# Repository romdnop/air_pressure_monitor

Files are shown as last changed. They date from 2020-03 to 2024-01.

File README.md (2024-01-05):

# About

Design files of an interface board for automotive application, the purpose of the board is data acquisition from air pressure sensors, CAN-Bus data sniffing and its relaying through one of the available interfaces.

# Features

* STM32F072 as a control MCU
* One side components placement
* Reverse-polarity protection, over-voltage protection and engine start surge voltage protection as decribed in [here](https://www.ti.com/lit/an/snva717/snva717.pdf)
* Support of two air-pressure sensors with 4-20mA interface
* USBx1
* CANx1
* RS485x1
* Support of extension boards with 2.54mm step (makes prototyping easier)

# Schematics
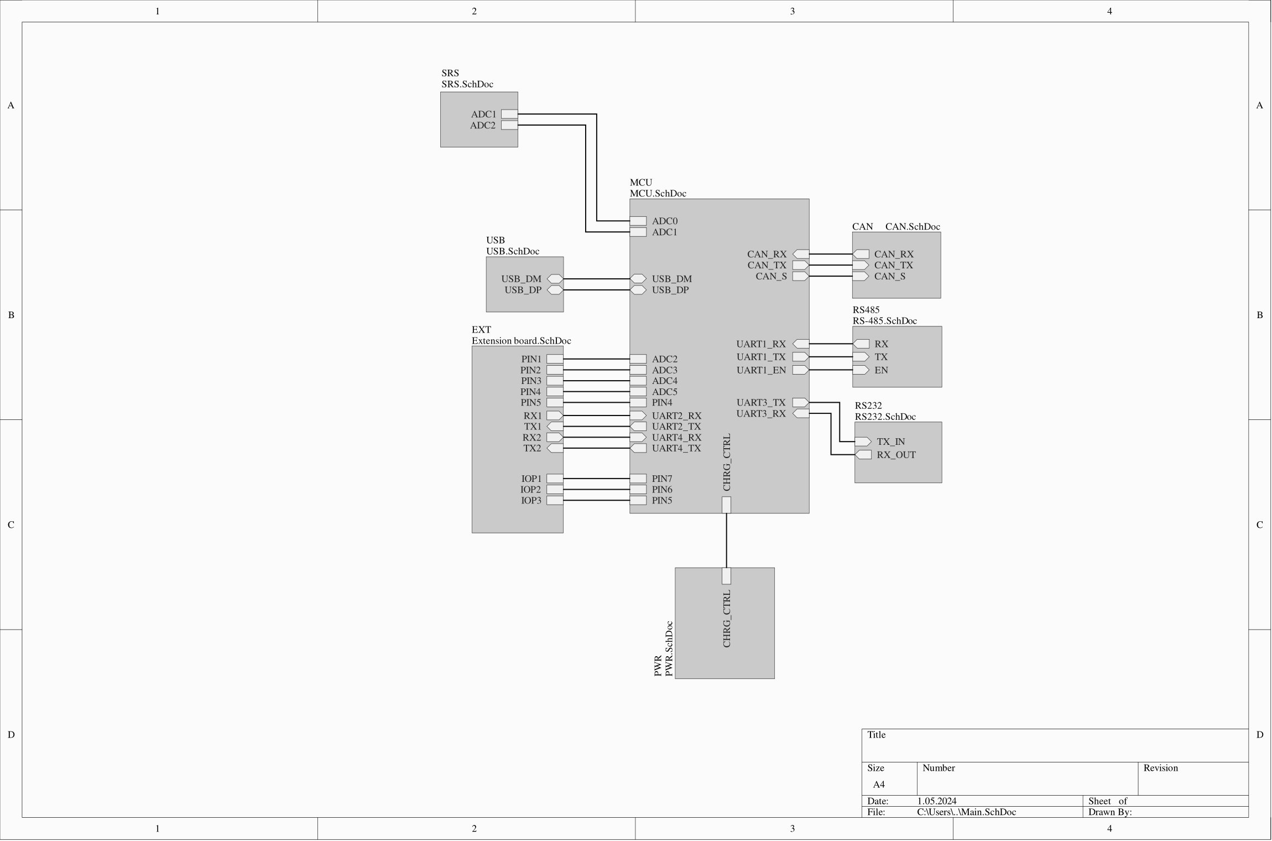
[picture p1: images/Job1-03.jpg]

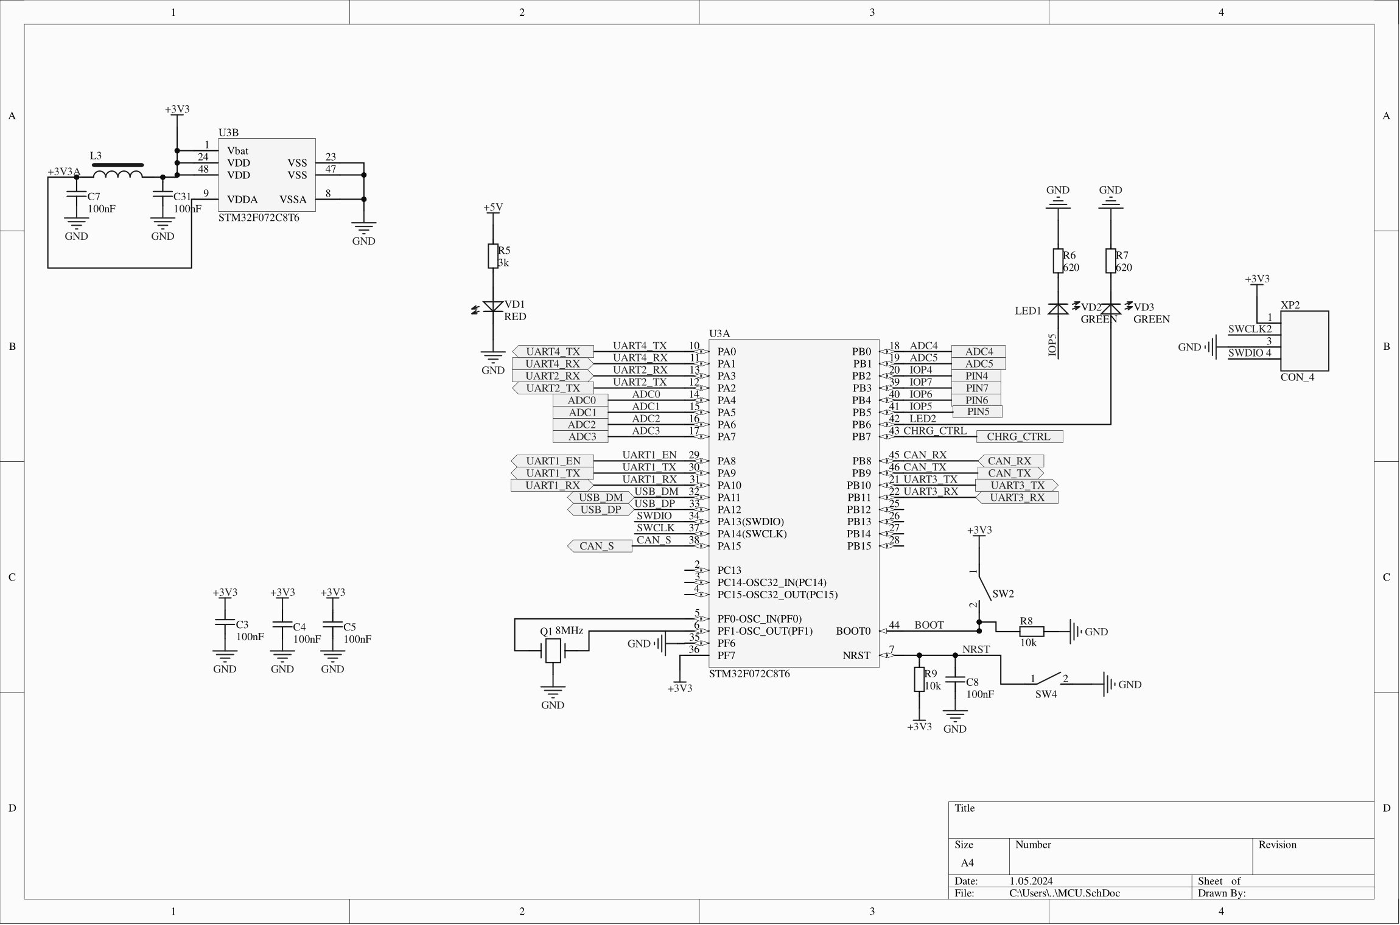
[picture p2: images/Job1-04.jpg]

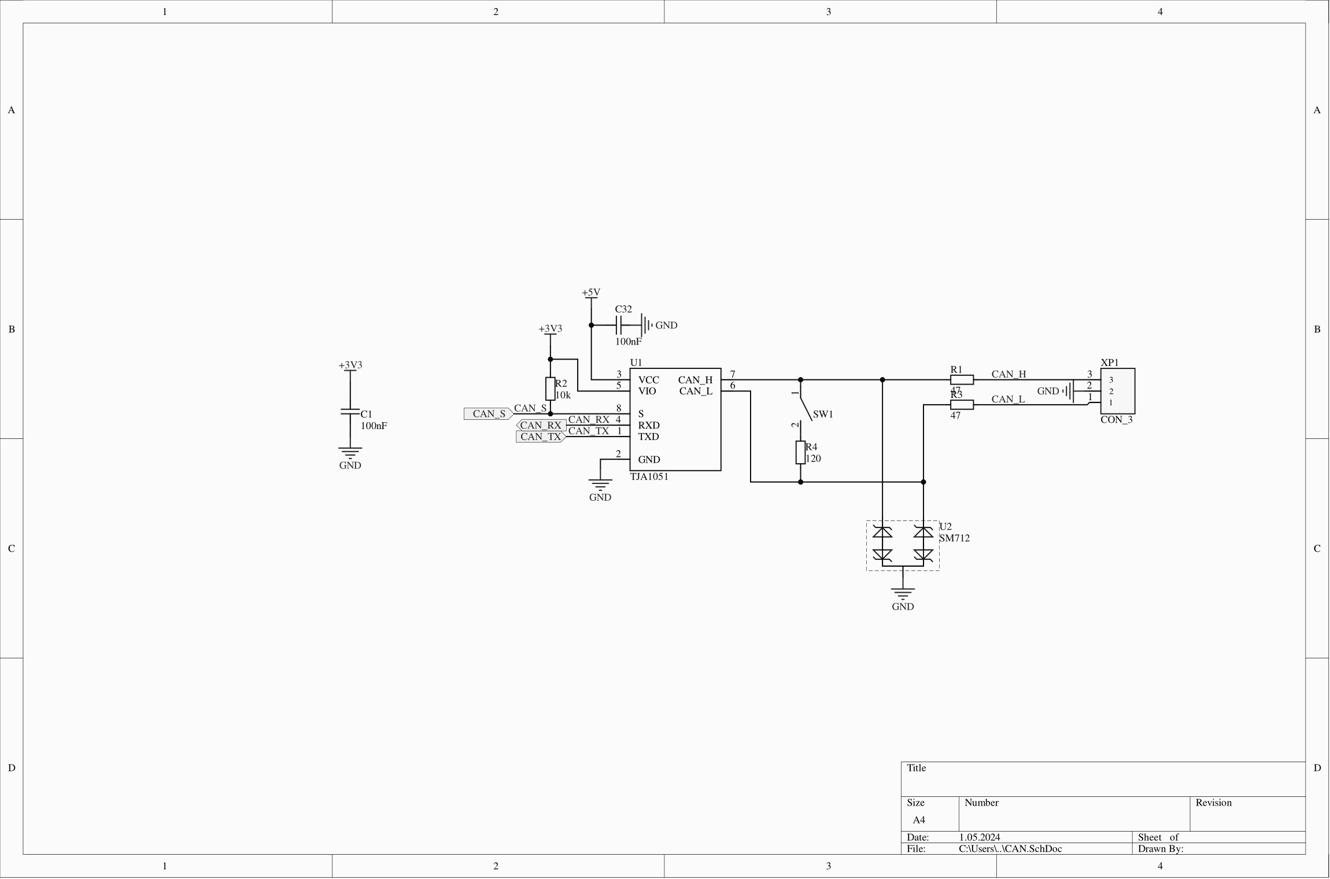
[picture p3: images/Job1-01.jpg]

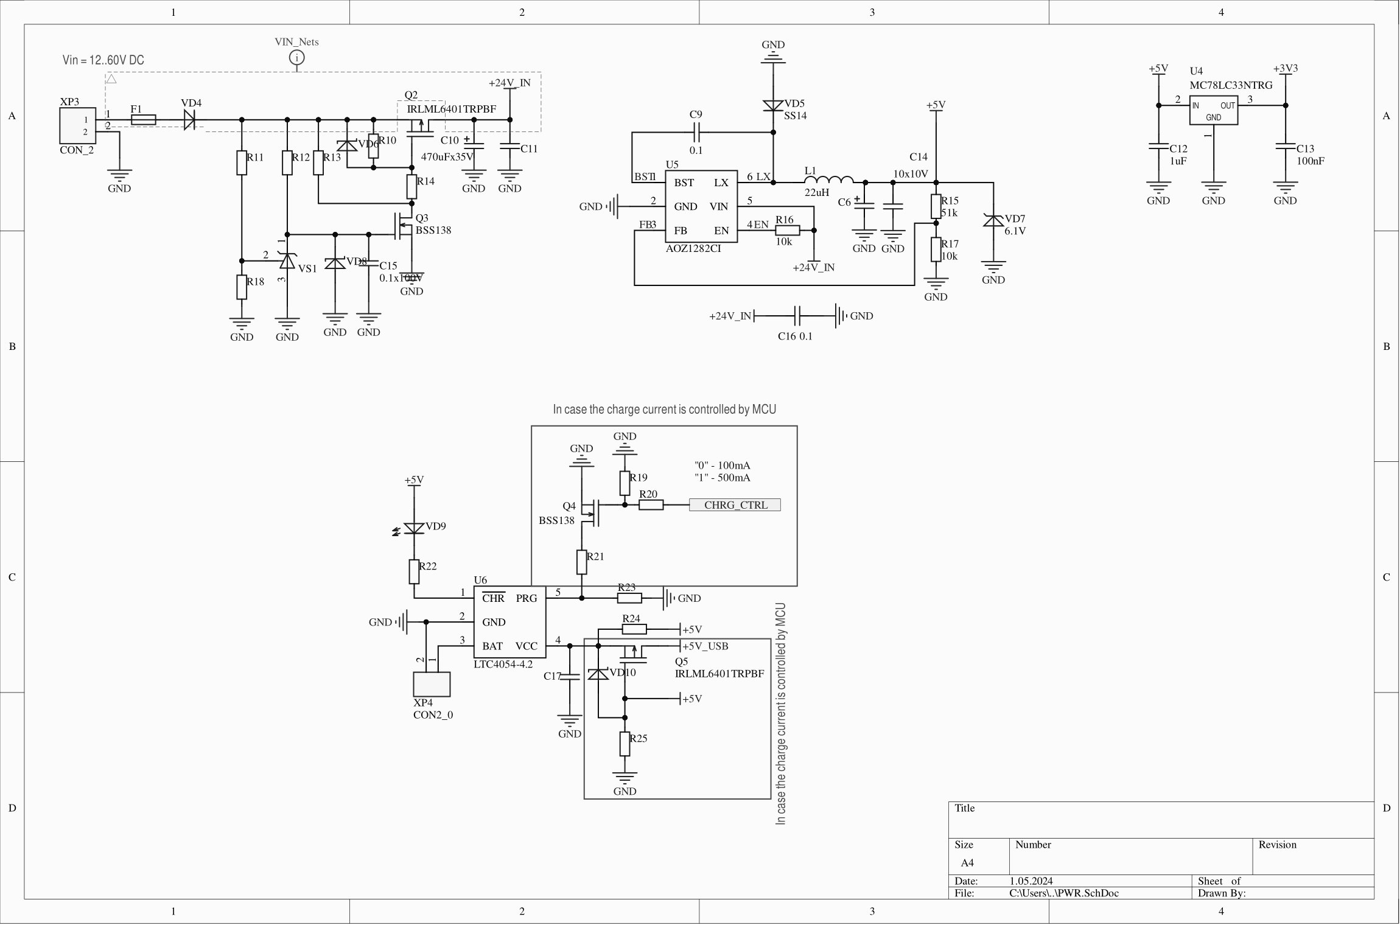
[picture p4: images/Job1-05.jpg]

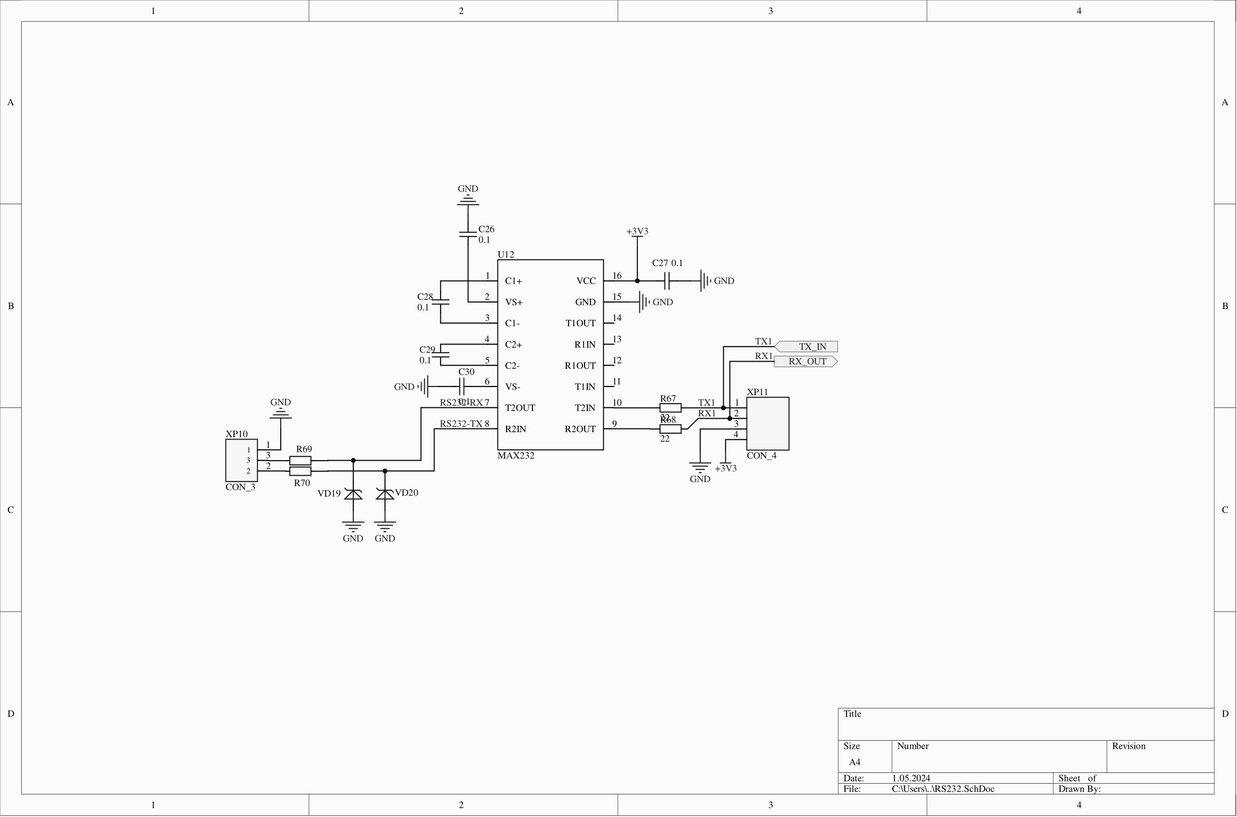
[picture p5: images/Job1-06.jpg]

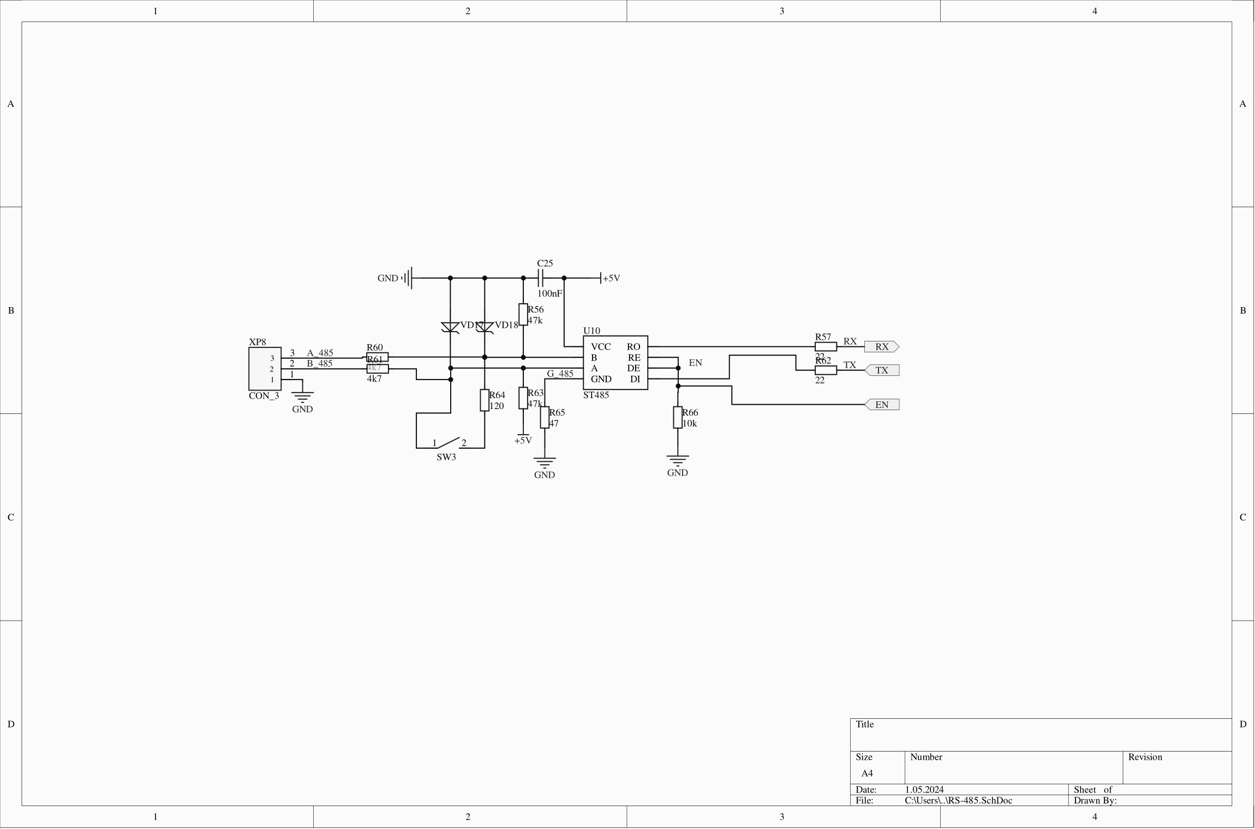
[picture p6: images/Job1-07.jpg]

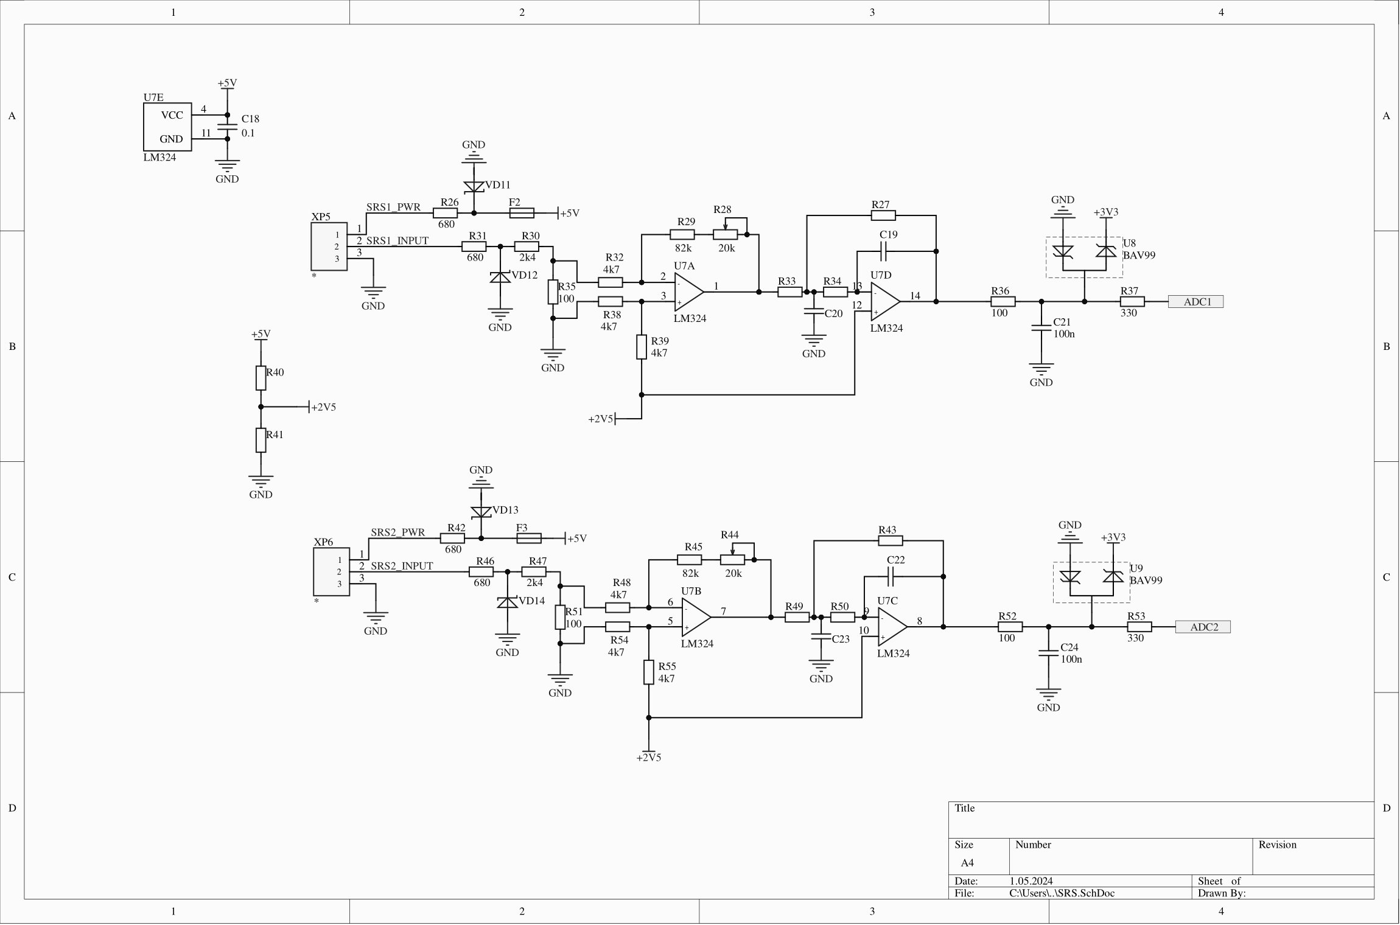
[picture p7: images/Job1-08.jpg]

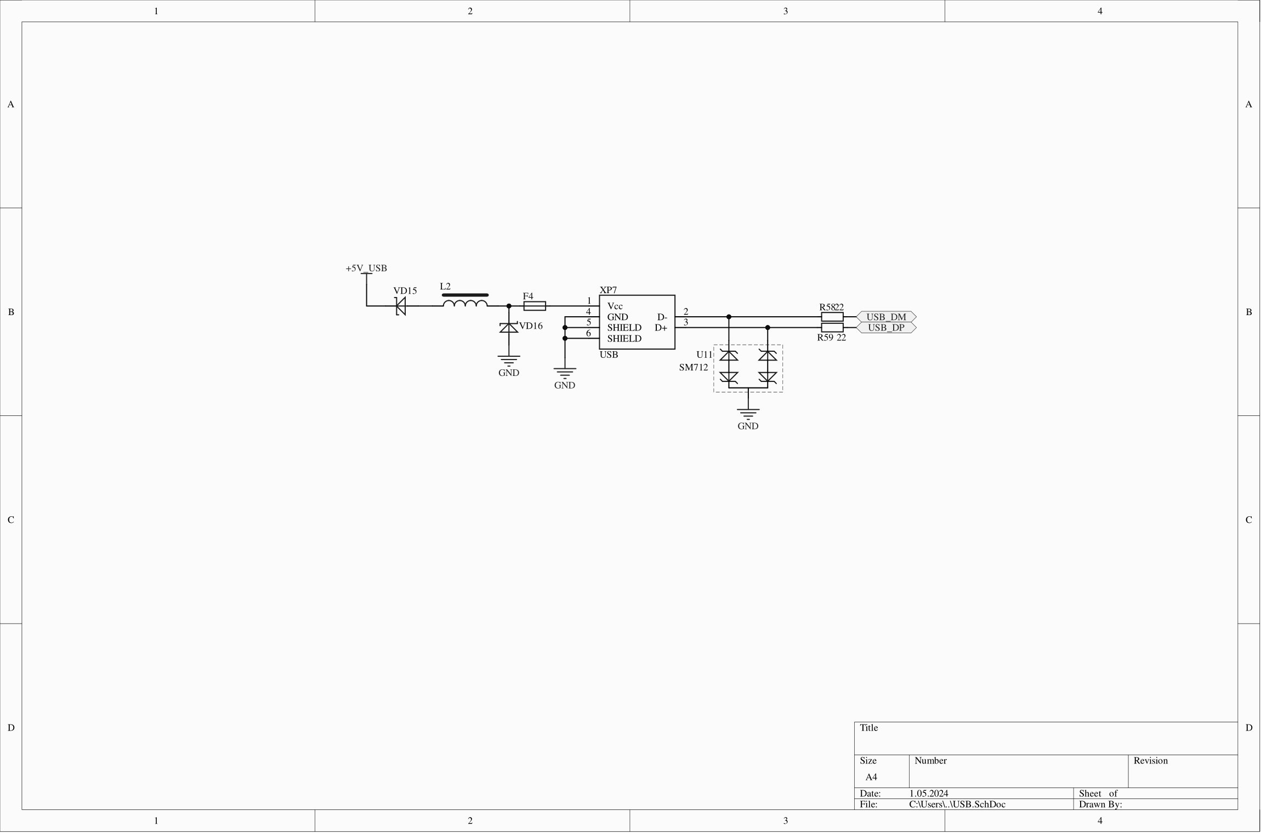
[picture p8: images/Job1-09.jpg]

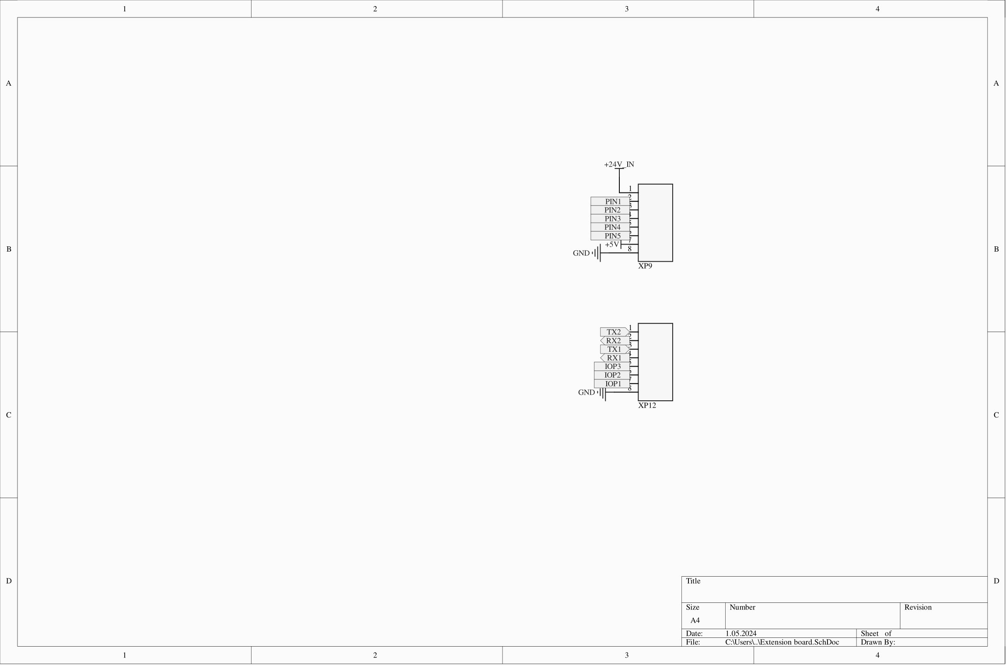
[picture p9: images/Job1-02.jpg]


# PCB
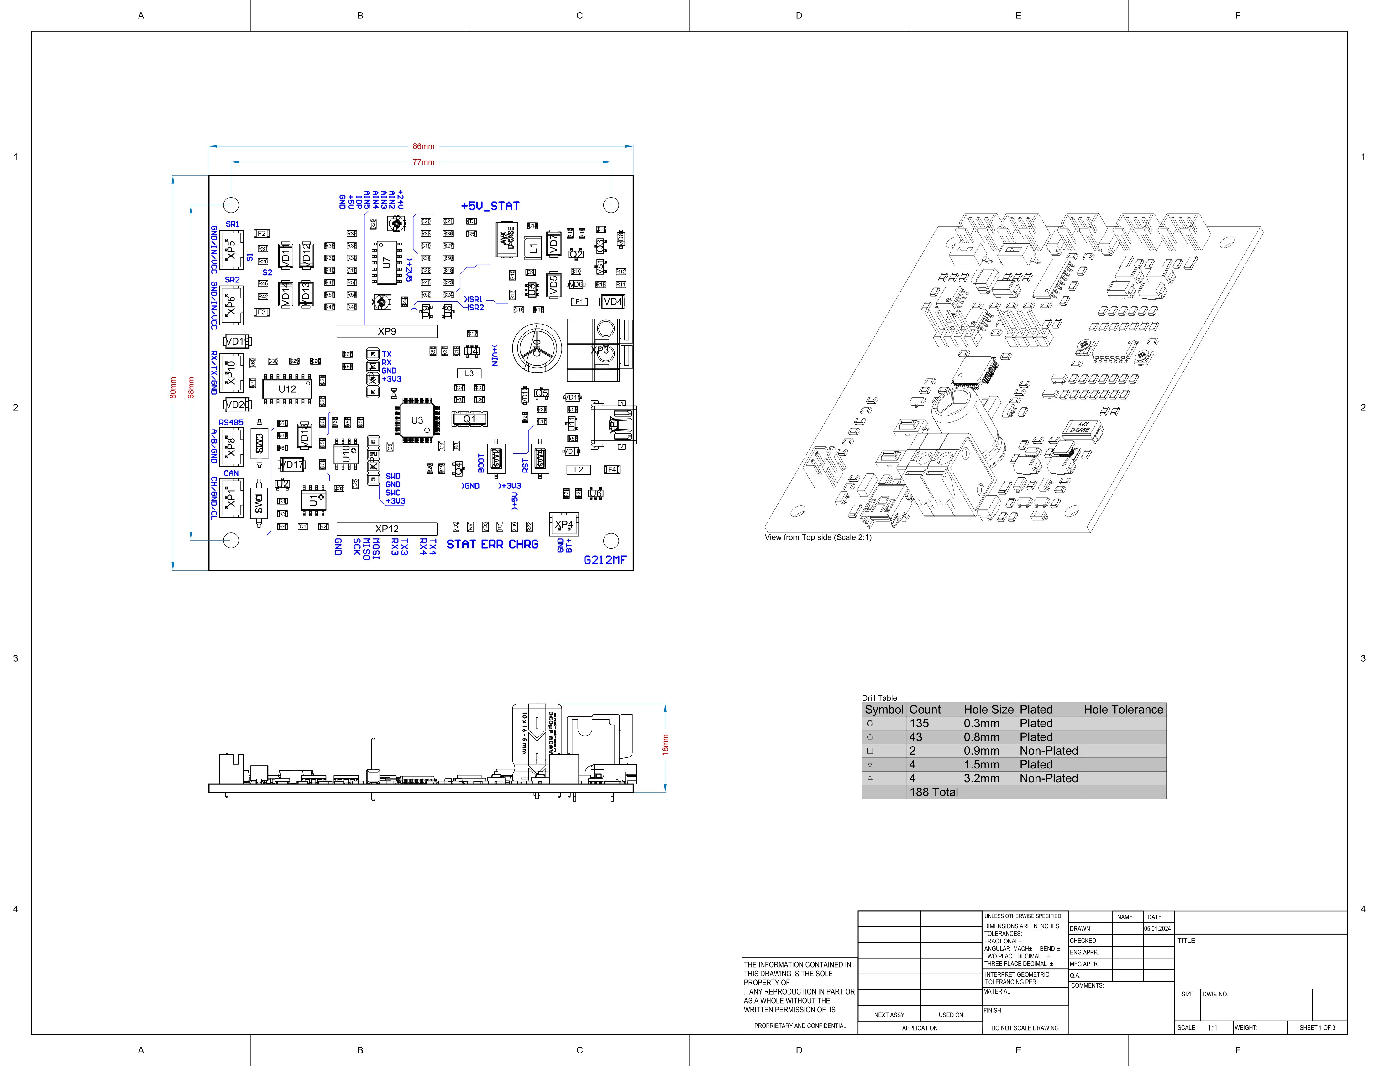
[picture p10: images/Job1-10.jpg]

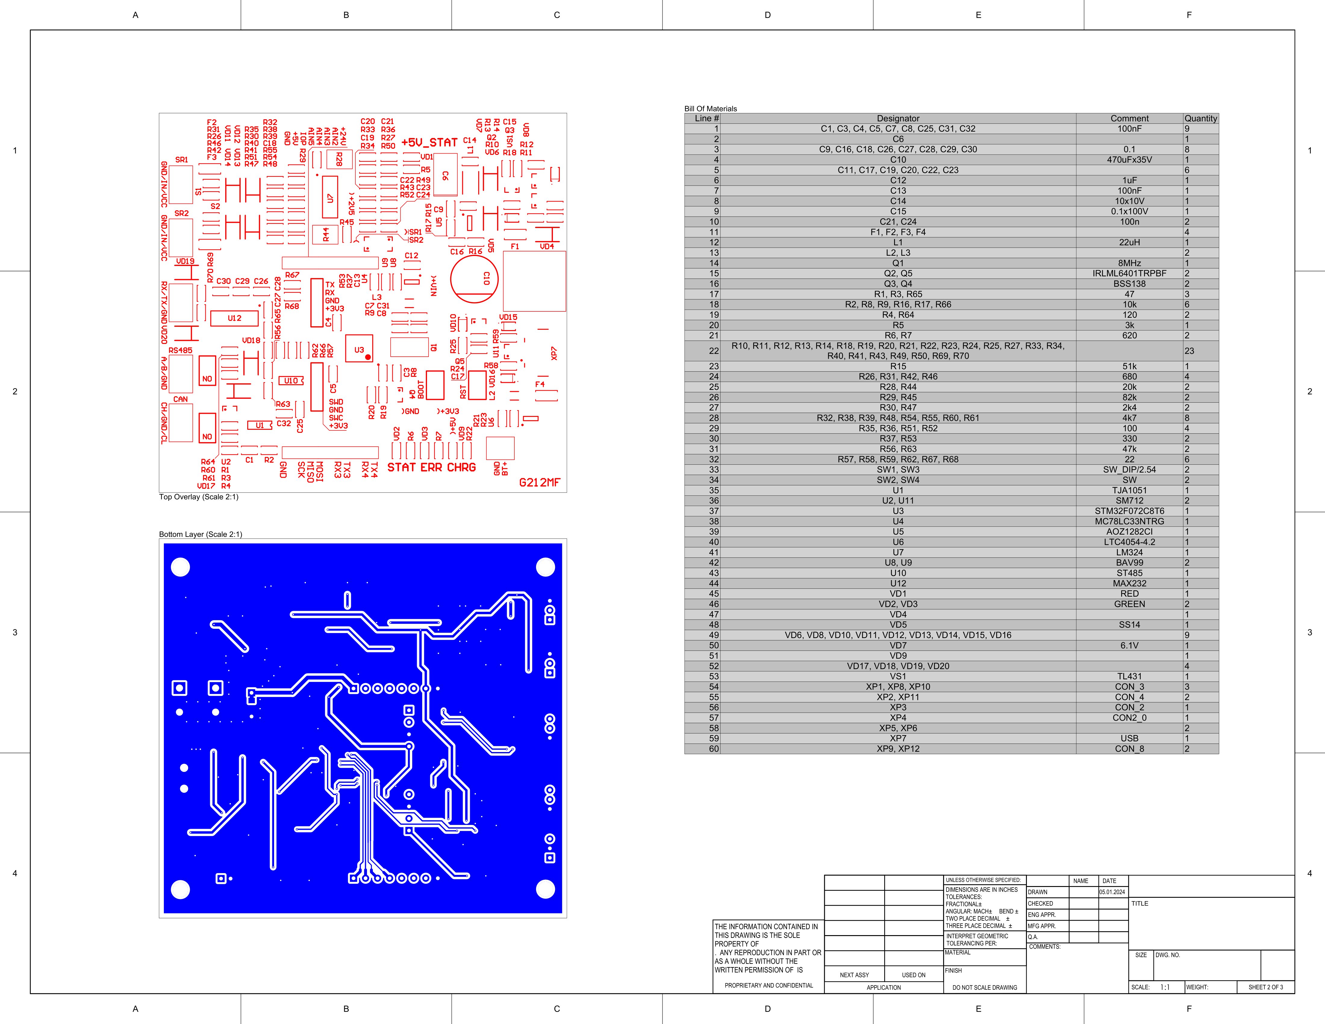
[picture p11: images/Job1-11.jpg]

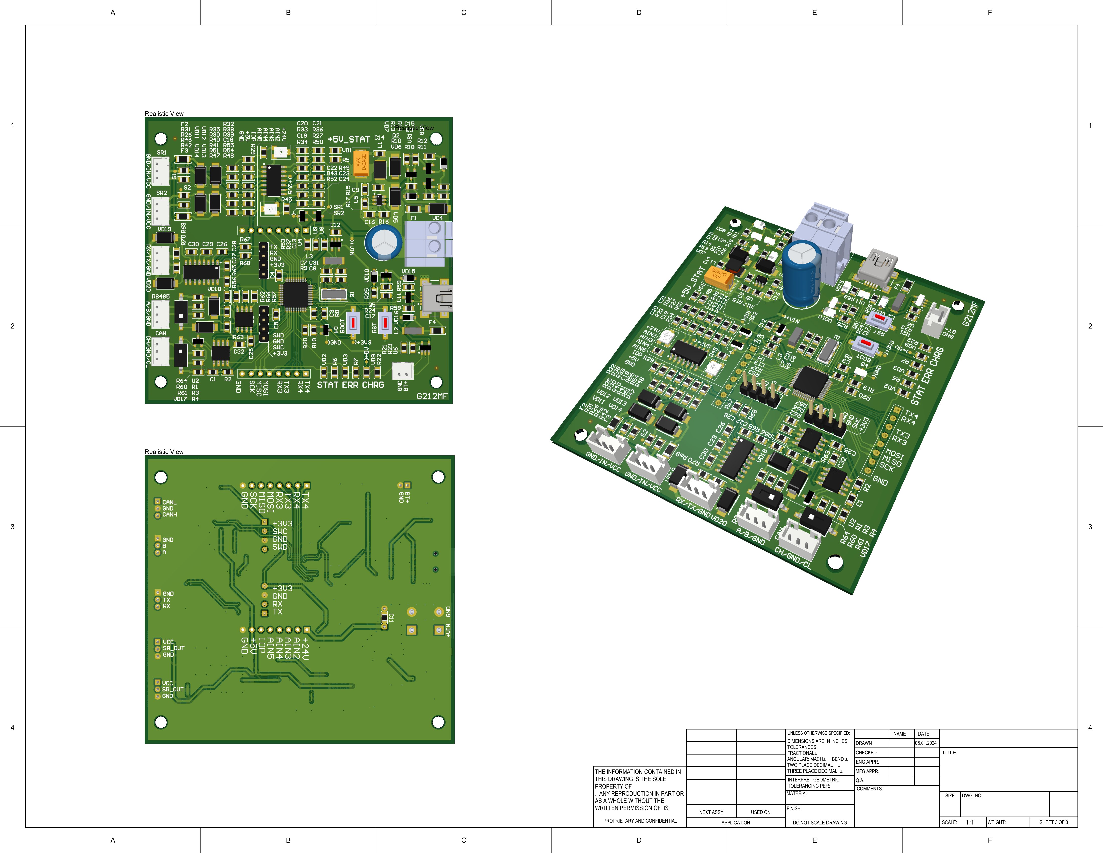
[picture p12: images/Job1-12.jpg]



# 3D view
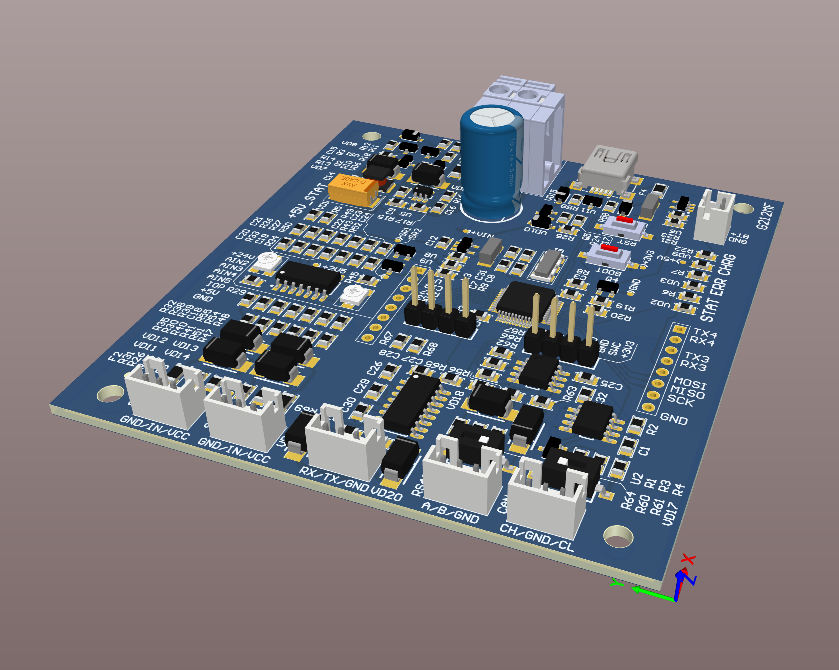
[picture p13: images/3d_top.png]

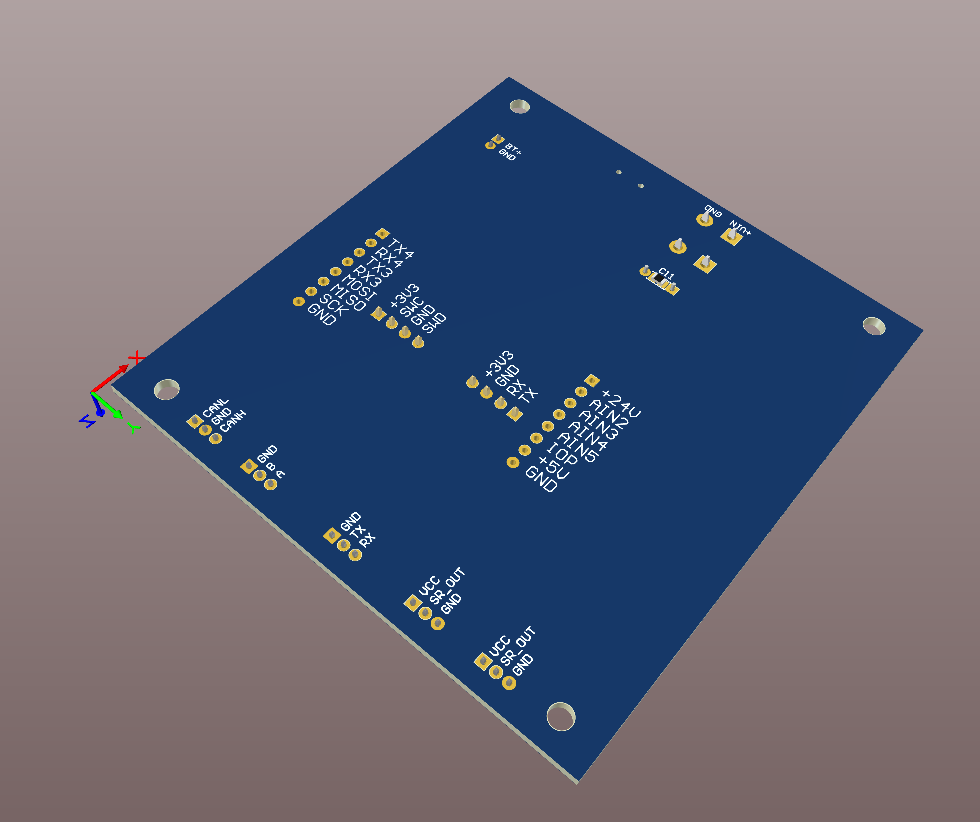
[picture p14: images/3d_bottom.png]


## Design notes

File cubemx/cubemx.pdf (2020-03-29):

## cubemx Project Configuration Report

# 1. Description

## 1.1. Project

Project Name | cubemx
Board Name | custom
Generated with: | STM32CubeMX 5.6.0
Date | 03/26/2020

## 1.2. MCU

MCU Series | STM32F0
MCU Line | STM32F0x2
MCU name | STM32F072CBTx
MCU Package | LQFP48
MCU Pin number | 48

# 2. Pinout Configuration

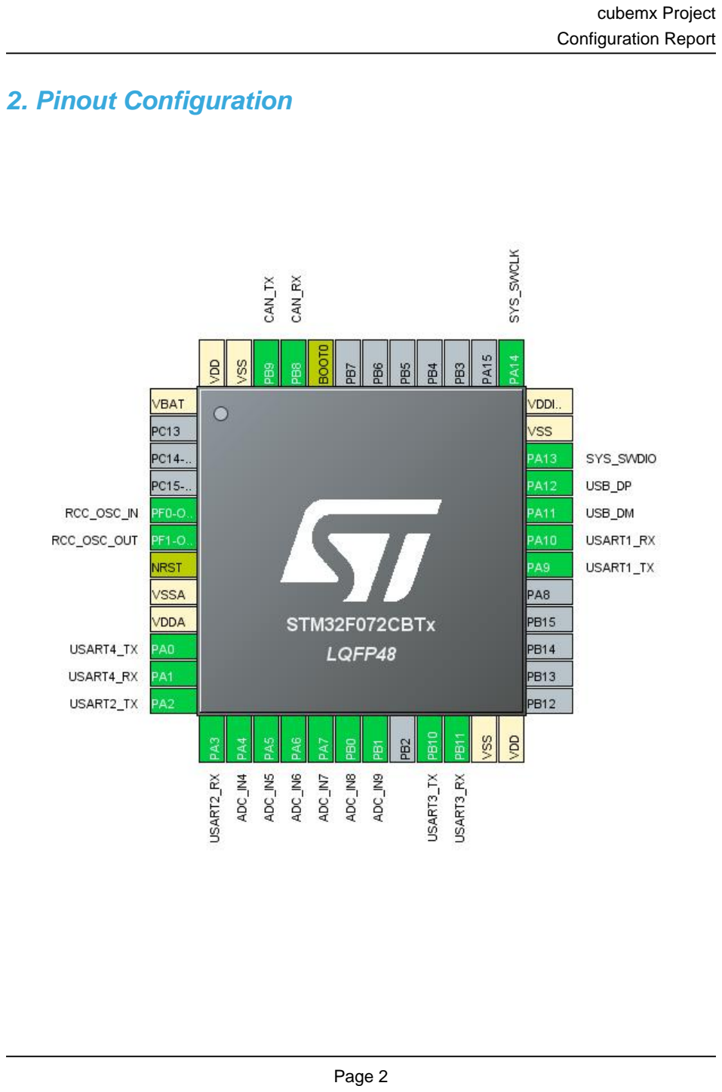
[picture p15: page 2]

# 3. Pins Configuration

Pin Number LQFP48 | Pin Name (function after reset) | Pin Type | Alternate Function(s) | Label
1 | VBAT | Power
5 | PF0-OSC_IN | I/O | RCC_OSC_IN
6 | PF1-OSC_OUT | I/O | RCC_OSC_OUT
7 | NRST | Reset
8 | VSSA | Power
9 | VDDA | Power
10 | PA0 | I/O | USART4_TX
11 | PA1 | I/O | USART4_RX
12 | PA2 | I/O | USART2_TX
13 | PA3 | I/O | USART2_RX
14 | PA4 | I/O | ADC_IN4
15 | PA5 | I/O | ADC_IN5
16 | PA6 | I/O | ADC_IN6
17 | PA7 | I/O | ADC_IN7
18 | PB0 | I/O | ADC_IN8
19 | PB1 | I/O | ADC_IN9
21 | PB10 | I/O | USART3_TX
22 | PB11 | I/O | USART3_RX
23 | VSS | Power
24 | VDD | Power
30 | PA9 | I/O | USART1_TX
31 | PA10 | I/O | USART1_RX
32 | PA11 | I/O | USB_DM
33 | PA12 | I/O | USB_DP
34 | PA13 | I/O | SYS_SWDIO
35 | VSS | Power
36 | VDDIO2 | Power
37 | PA14 | I/O | SYS_SWCLK
44 | BOOT0 | Boot
45 | PB8 | I/O | CAN_RX
46 | PB9 | I/O | CAN_TX
47 | VSS | Power
48 | VDD | Power

# 4. Clock Tree Configuration

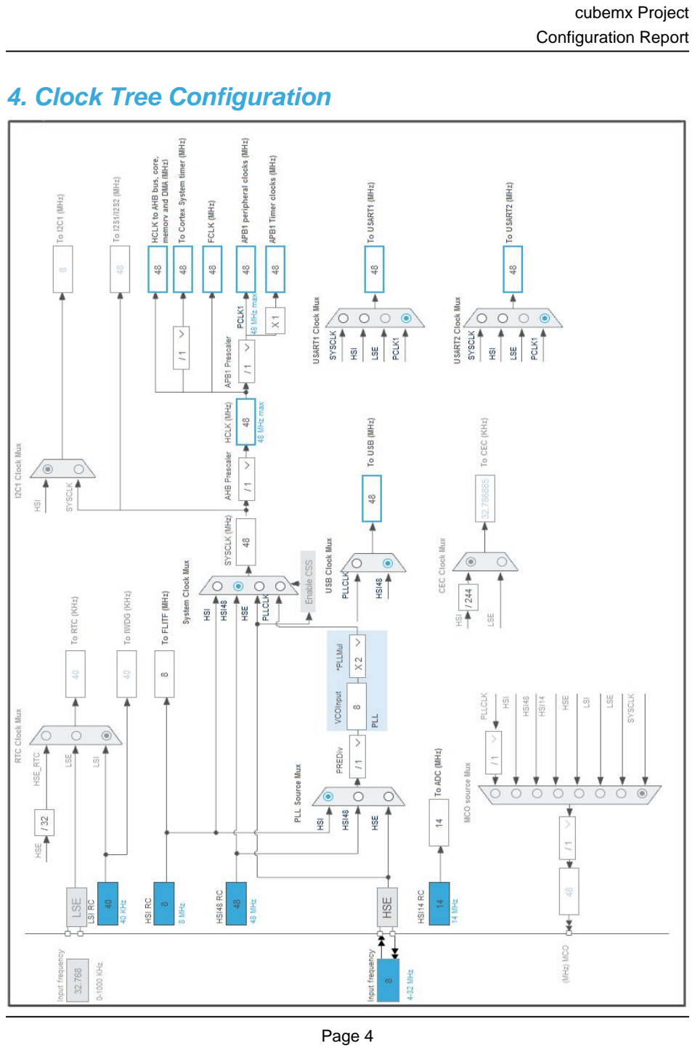
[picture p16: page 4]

# 5. Software Project

## 5.1. Project Settings

Name | Value
Project Name | cubemx
Project Folder | D:\Altium\Projects\TrailerController_SuspensionPMS\cubemx
Toolchain / IDE | EWARM V8.32
Firmware Package Name and Version | STM32Cube FW_F0 V1.11.0

## 5.2. Code Generation Settings

Name | Value
STM32Cube MCU packages and embedded software | Copy all used libraries into the project folder
Generate peripheral initialization as a pair of '.c/.h' files | No
Backup previously generated files when re-generating | No
Delete previously generated files when not re-generated | Yes
Set all free pins as analog (to optimize the power consumption) | No

# 6. Power Consumption Calculator report

### 6.1. Microcontroller Selection

Series | STM32F0
Line | STM32F0x2
MCU | STM32F072CBTx
Datasheet | 025004_Rev5

### 6.2. Parameter Selection

Temperature | 25
Vdd | 3.6

### 6.3. Battery Selection

Battery | Li-SOCL2(A3400)
Capacity | 3400.0 mAh
Self Discharge | 0.08 %/month
Nominal Voltage | 3.6 V
Max Cont Current | 100.0 mA
Max Pulse Current | 200.0 mA
Cells in series | 1
Cells in parallel | 1

## 6.4. Sequence

Step | Step1 | Step2
Mode | RUN | STOP
Vdd | 3.6 | 3.6
Voltage Source | Battery | Battery
Range | No Scale | No Scale
Fetch Type | FLASH | n/a
CPU Frequency | 48 MHz | 0 Hz
Clock Configuration | HSE PLL | Regulator_LP
Clock Source Frequency | 8 MHz | 0 Hz

### Peripherals

Additional Cons. | 0 mA | 0 mA
Average Current | 13.66 mA | 6.5 µA
Duration | 0.1 ms | 0.9 ms
DMIPS | 0.0 | 0.0
Ta Max | 102.34 | 105
Category | In DS Table | In DS Table

## 6.5. RESULTS

Sequence Time | 1 ms | Average Current | 1.37 mA
Battery Life | 3 months, 11 days, 17 hours | Average DMIPS | 0.0 DMIPS

## 6.6. Chart

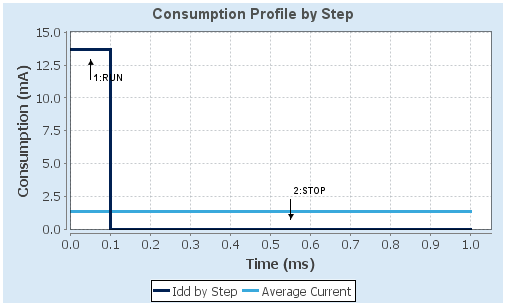
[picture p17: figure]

# 7. IPs and Middleware Configuration

# 7.1. ADC

## mode: IN4 mode: IN5 mode: IN6 mode: IN7 mode: IN8 mode: IN9 7.1.1. Parameter Settings:

### ADC_Settings:

Clock Prescaler | Asynchronous clock mode
Resolution | ADC 12-bit resolution
Data Alignment | Right alignment
Scan Conversion Mode | Forward
Continuous Conversion Mode | Disabled
Discontinuous Conversion Mode | Disabled
DMA Continuous Requests | Disabled
End Of Conversion Selection | End of single conversion
Overrun behaviour | Overrun data preserved
Low Power Auto Wait | Disabled
Low Power Auto Power Off | Disabled

### ADC_Regular_ConversionMode:

Sampling Time | 1.5 Cycles
External Trigger Conversion Source | Regular Conversion launched by software
External Trigger Conversion Edge | None

### WatchDog:

Enable Analog WatchDog Mode | false

# 7.2. CAN

## mode: Mode 7.2.1. Parameter Settings:

### Bit Timings Parameters:

Prescaler (for Time Quantum) | 16
Time Quantum | 333.3333333333333 *
Time Quanta in Bit Segment 1 | 1 Time

Time Quanta in Bit Segment 2 | 1 Time
ReSynchronization Jump Width | 1 Time

### Basic Parameters:

Time Triggered Communication Mode | Disable
Automatic Bus-Off Management | Disable
Automatic Wake-Up Mode | Disable
Automatic Retransmission | Disable
Receive Fifo Locked Mode | Disable
Transmit Fifo Priority | Disable

### Advanced Parameters:

Operating Mode | Normal

# 7.3. CRC

## mode: Activated 7.3.1. Parameter Settings:

### Basic Parameters:

Default Polynomial State | Enable
Default Init Value State | Enable

### Advanced Parameters:

Input Data Inversion Mode | None
Output Data Inversion Mode | Disable
Input Data Format | Bytes

# 7.4. GPIO

# 7.5. RCC

## High Speed Clock (HSE): Crystal/Ceramic Resonator 7.5.1. Parameter Settings:

### System Parameters:

VDD voltage (V) | 3.3
Prefetch Buffer | Enabled
Flash Latency(WS) | 1 WS (2 CPU cycle)

### RCC Parameters:

HSI14 Calibration Value | 16

HSE Startup Timout Value (ms) | 100
LSE Startup Timout Value (ms) | 5000

# 7.6. SYS

## mode: Debug Serial Wire Timebase Source: SysTick

# 7.7. USART1

## Mode: Asynchronous 7.7.1. Parameter Settings:

### Basic Parameters:

Baud Rate | 38400
Word Length | 8 Bits (including Parity)
Parity | None
Stop Bits | 1

### Advanced Parameters:

Data Direction | Receive and Transmit
Over Sampling | 16 Samples
Single Sample | Disable

### Advanced Features:

Auto Baudrate | Disable
TX Pin Active Level Inversion | Disable
RX Pin Active Level Inversion | Disable
Data Inversion | Disable
TX and RX Pins Swapping | Disable
Overrun | Enable
DMA on RX Error | Enable
MSB First | Disable

# 7.8. USART2

## Mode: Asynchronous 7.8.1. Parameter Settings:

### Basic Parameters:

Baud Rate | 38400

Word Length | 8 Bits (including Parity)
Parity | None
Stop Bits | 1

### Advanced Parameters:

Data Direction | Receive and Transmit
Over Sampling | 16 Samples
Single Sample | Disable

### Advanced Features:

Auto Baudrate | Disable
TX Pin Active Level Inversion | Disable
RX Pin Active Level Inversion | Disable
Data Inversion | Disable
TX and RX Pins Swapping | Disable
Overrun | Enable
DMA on RX Error | Enable
MSB First | Disable

# 7.9. USART3

## Mode: Asynchronous 7.9.1. Parameter Settings:

### Basic Parameters:

Baud Rate | 38400
Word Length | 8 Bits (including Parity)
Parity | None
Stop Bits | 1

### Advanced Parameters:

Data Direction | Receive and Transmit
Over Sampling | 16 Samples
Single Sample | Disable

### Advanced Features:

TX Pin Active Level Inversion | Disable
RX Pin Active Level Inversion | Disable
Data Inversion | Disable
TX and RX Pins Swapping | Disable
Overrun | Enable
DMA on RX Error | Enable
MSB First | Disable

# 7.10. USART4

## Mode: Asynchronous 7.10.1. Parameter Settings:

### Basic Parameters:

Baud Rate | 38400
Word Length | 8 Bits (including Parity)
Parity | None
Stop Bits | 1

### Advanced Parameters:

Data Direction | Receive and Transmit
Over Sampling | 16 Samples
Single Sample | Disable

### Advanced Features:

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

# 7.11. USB

## mode: Device (FS) 7.11.1. Parameter Settings:

### Basic Parameters:

Speed | Full Speed 12MBit/s
Physical interface | Internal Phy

### Power Parameters:

Low Power | Disabled
Link Power Management | Disabled

### * User modified value

# 8. System Configuration

# 8.1. GPIO configuration

IP | Pin | Signal | GPIO mode | GPIO pull/up pull down | Max Speed | User Label
ADC | PA4 | ADC_IN4 | Analog mode | No pull-up and no pull-down | n/a
| PA5 | ADC_IN5 | Analog mode | No pull-up and no pull-down | n/a
| PA6 | ADC_IN6 | Analog mode | No pull-up and no pull-down | n/a
| PA7 | ADC_IN7 | Analog mode | No pull-up and no pull-down | n/a
| PB0 | ADC_IN8 | Analog mode | No pull-up and no pull-down | n/a
| PB1 | ADC_IN9 | Analog mode | No pull-up and no pull-down | n/a
CAN | PB8 | CAN_RX | Alternate Function Push Pull | No pull-up and no pull-down | High *
| PB9 | CAN_TX | Alternate Function Push Pull | No pull-up and no pull-down | High *
RCC | PF0-OSC_IN | RCC_OSC_IN | n/a | n/a | n/a
| PF1-OSC_OUT | RCC_OSC_OUT | n/a | n/a | n/a
SYS | PA13 | SYS_SWDIO | n/a | n/a | n/a
| PA14 | SYS_SWCLK | n/a | n/a | n/a
USART1 | PA9 | USART1_TX | Alternate Function Push Pull | No pull-up and no pull-down | High *
| PA10 | USART1_RX | Alternate Function Push Pull | No pull-up and no pull-down | High *
USART2 | PA2 | USART2_TX | Alternate Function Push Pull | No pull-up and no pull-down | High *
| PA3 | USART2_RX | Alternate Function Push Pull | No pull-up and no pull-down | High *
USART3 | PB10 | USART3_TX | Alternate Function Push Pull | No pull-up and no pull-down | High *
| PB11 | USART3_RX | Alternate Function Push Pull | No pull-up and no pull-down | High *
USART4 | PA0 | USART4_TX | Alternate Function Push Pull | No pull-up and no pull-down | High *
| PA1 | USART4_RX | Alternate Function Push Pull | No pull-up and no pull-down | High *
USB | PA11 | USB_DM | n/a | n/a | n/a
| PA12 | USB_DP | n/a | n/a | n/a

# 8.2. DMA configuration

## nothing configured in DMA service

# 8.3. NVIC configuration

Interrupt Table | Enable | Preenmption Priority | SubPriority
Non maskable interrupt | true | 0 | 0
Hard fault interrupt | true | 0 | 0
System service call via SWI instruction | true | 0 | 0
Pendable request for system service | true | 0 | 0
System tick timer | true | 0 | 0
PVD and VDDIO2 supply comparator interrupts through EXTI lines 16 and 31 | unused
Flash global interrupt | unused
RCC and CRS global interrupts | unused
ADC and COMP interrupts (COMP interrupts through EXTI lines 21 and 22) | unused
USART1 global interrupt / USART1 wake-up interrupt through EXTI line 25 | unused
USART2 global interrupt / USART2 wake-up interrupt through EXTI line 26 | unused
USART3 and USART4 global interrupts | unused
HDMI-CEC and CAN interrupts / HDMI-CEC wake-up interrupt through EXTI line 27 | unused
USB global interrupt / USB wake-up interrupt through EXTI line 18 | unused

### * User modified value

# 9. Predefined Views - Category view : Current

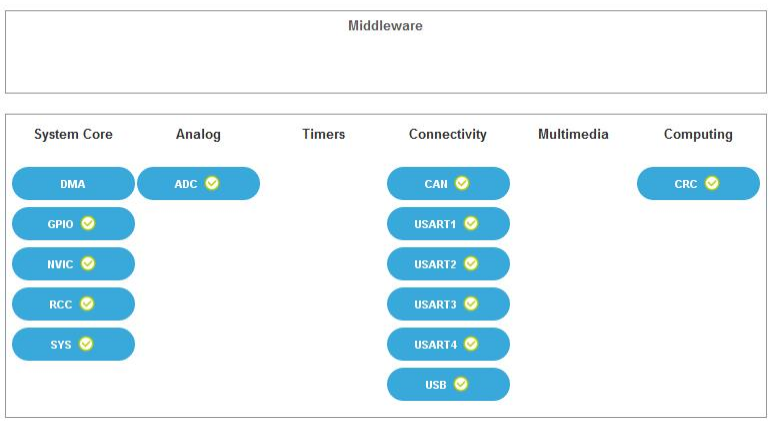
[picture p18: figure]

# 10. Software Pack Report

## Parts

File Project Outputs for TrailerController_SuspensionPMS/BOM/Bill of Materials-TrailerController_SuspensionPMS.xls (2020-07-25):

Comment | Description | Designator | Footprint | LibRef | Quantity
100nF | None polar capacitor | C1, C3, C4, C5, C8, C13 | SMD_0805 | C_NONE_POLAR | 6
 | Polar capacitor | C6 | SMD_Tantalum_CAP-D | C_POLAR | 1
 | None polar capacitor, None polar capacitor, None polar capacitor, None polar capacitor, None polar capacitor, None polar capacitor, None polar capacitor, None polar capacitor, None polar capacitor, None polar capacitor, Resistor, Resistor, Resistor, Resistor, Resistor, Resistor, Resistor, Resistor, Resistor, Resistor, Resistor, Resistor, Resistor, Resistor, Resistor, Resistor, Resistor, Resistor, Resistor, Resistor, Resistor, Resistor, Resistor, Resistor, Resistor, Resistor, Resistor, Resistor, Resistor, Resistor, Resistor, Resistor, Resistor, Resistor, Resistor, Resistor, LED | C7, C11, C17, C19, C20, C22, C23, C25, C31, C32, R1, R3, R10, R11, R12, R13, R14, R18, R19, R20, R21, R22, R23, R24, R25, R27, R33, R34, R40, R41, R43, R49, R50, R56, R57, R60, R61, R62, R63, R64, R65, R66, R67, R68, R69, R70, VD9 | SMD_0805 | C_NONE_POLAR, C_NONE_POLAR, C_NONE_POLAR, C_NONE_POLAR, C_NONE_POLAR, C_NONE_POLAR, C_NONE_POLAR, C_NONE_POLAR, C_NONE_POLAR, C_NONE_POLAR, RES, RES, RES, RES, RES, RES, RES, RES, RES, RES, RES, RES, RES, RES, RES, RES, RES, RES, RES, RES, RES, RES, RES, RES, RES, RES, RES, RES, RES, RES, RES, RES, RES, RES, RES, RES, LED | 47
0.1 | None polar capacitor | C9, C16, C18, C26, C27, C28, C29, C30 | SMD_0805 | C_NONE_POLAR | 8
470uFx35V | Polar capacitor | C10 | CAPR-10/5 | C_POLAR | 1
1uF | None polar capacitor | C12 | SMD_0805 | C_NONE_POLAR | 1
10x10V | None polar capacitor | C14 | SMD_0805 | C_NONE_POLAR | 1
0.1x100V | None polar capacitor | C15 | SMD_0805 | C_NONE_POLAR | 1
100n | None polar capacitor | C21, C24 | SMD_0805 | C_NONE_POLAR | 2
 | Resistor | F1, F2, F3, F4 | SMD_1206 | FUSE | 4
22uH |  | L1 | IND-1812 | INDUCTOR | 1
 | Ferrite Bread | L2, L3 | INDC4516AM | FB | 2
8MHz | Crystal oscillator | Q1 | CSTCC-CRYSTAL | CRYSTAL_CAP | 1
IRLML6401TRPBF | P-Channel | Q2, Q5 | SOT23-3PIN | IRLML6401TRPBF | 2
BSS138 | IG-FET N-Channel | Q3, Q4 | SOT23-3PIN | BSS138 | 2
10k | Resistor | R2, R8, R9, R16, R17 | SMD_0805 | RES | 5
120 | Resistor | R4 | SMD_0805 | RES | 1
3k | Resistor | R5 | SMD_0805 | RES | 1
620 | Resistor | R6, R7 | SMD_0805 | RES | 2
51k | Resistor | R15 | SMD_0805 | RES | 1
680 | Resistor | R26, R31, R42, R46 | SMD_0805 | RES | 4
20k | Agjustable resistor | R28, R44 | RES-ADJ-SMD-Panasonic | RES_ADJ | 2
82k | Resistor | R29, R45 | SMD_0805 | RES | 2
2k4 | Resistor | R30, R47 | SMD_0805 | RES | 2
4k7 | Resistor | R32, R38, R39, R48, R54, R55 | SMD_0805 | RES | 6
100 | Resistor | R35, R36, R51, R52 | SMD_0805 | RES | 4
330 | Resistor | R37, R53 | SMD_0805 | RES | 2
22 | Resistor | R58, R59 | SMD_0805 | RES | 2
SW_DIP/2.54 | Switch | SW1, SW3 | DIP-SW/2.54/1 | SW | 2
SW | Switch | SW2, SW4 | SW_6/3.7 | SW | 2
TJA1051 |  | U1 | SO8-150mil | TJA1051 | 1
SM712 | TVS diodes | U2, U11 | SOT23-3 | SM712 | 2
STM32F072C8T6 | ARM Cortex-M0 32-bit MCU, 64 KB Flash, 8 KB Internal RAM, 39 I/Os, 48-pin LQFP, -40 to 85 degC, Tray | U3 | STM-LQFP48_L | STM32F072C8T6 | 1
MC78LC33NTRG | Low dropout Linear Voltage Regulator | U4 | SOT753 | MC78LC33NTRG | 1
AOZ1282CI | Buck regulator | U5 | SOT-23-6 | AOZ1282CI | 1
LTC4054-4.2 | Buck regulator | U6 | SOT753 | LTC4054-4.2 | 1
LM324 | OpAmp | U7 | SOIC-14 | LM324 | 1
BAV99 | TVS diodes | U8, U9 | SOT23-3 | BAV99 | 2
ST485 | RS485 interface | U10 | SO8-150mil | ST485 | 1
MAX232 | RS232 transceiver | U12 | SOIC-16 | MAX232 | 1
RED |  | VD1 | SMD_0805 | LED | 1
GREEN |  | VD2, VD3 | SMD_0805 | LED | 2
 | Diode, Zener diode, Zener diode, Zener diode, Zener diode, TVS Diode, TVS Diode, TVS Diode, TVS Diode | VD4, VD11, VD12, VD13, VD14, VD17, VD18, VD19, VD20 | DO214-AC | DIODE, ZENER, ZENER, ZENER, ZENER, DIOSE_TVS, DIOSE_TVS, DIOSE_TVS, DIOSE_TVS | 9
SS14 | Diode | VD5 | DO214-AC | DIODE | 1
 | Zener diode | VD6, VD8, VD10, VD15, VD16 | SOD-123 | ZENER | 5
6.1V | TVS Diode | VD7 | DO214-AC | DIOSE_TVS | 1
TL431 |  | VS1 | SOT23-3 | TL431 | 1
CON_3 |  | XP1, XP8, XP10 | MW-3M-2.0 | CON_3 | 3
CON_4 |  | XP2, XP11 | HEAD-1/4/2.54 | CON_4 | 2
CON_2 |  | XP3 | DG142V-5.08-2 | CON_2 | 1
CON2_0 |  | XP4 | MW-2M-2.0 | CON2_0 | 1
 |  | XP5, XP6 | MW-3M-2.0 | CON_3 | 2
USB |  | XP7 | USB/SM0.8-6H5 | USB | 1
CON_8 |  | XP9, XP12 | HEAD-1/8/2.54 | CON_8 | 2

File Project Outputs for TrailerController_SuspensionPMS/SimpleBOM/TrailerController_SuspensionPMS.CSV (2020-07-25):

Bill of Material for
On 28.05.2020 at 12:08:58
Comment | Pattern | Quantity | Components
 | DO214-AC | 9 | VD4, VD11, VD12, VD13, VD14, VD17, VD18, VD19, VD20 | Diode
 | INDC4516AM | 2 | L2, L3 | Ferrite Bread
 | MW-3M-2.0 | 2 | XP5, XP6
 | SMD_0805 | 47 | C7, C11, C17, C19, C20, C22, C23, C25, C31, C32, R1, R3, R10, R11, R12, R13, R14, R18, R19, R20, R21, R22, R23, R24, R25, R27, R33, R34, R40, R41, R43, R49, R50, R56, R57, R60, R61, R62, R63, R64, R65, R66, R67, R68, R69, R70, VD9 | None polar capacitor
 | SMD_1206 | 4 | F1, F2, F3, F4 | Resistor
 | SMD_Tantalum_CAP-D | 1 | C6 | Polar capacitor
 | SOD-123 | 5 | VD6, VD8, VD10, VD15, VD16 | Zener diode
0.1 | SMD_0805 | 8 | C9, C16, C18, C26, C27, C28, C29, C30 | None polar capacitor
0.1x100V | SMD_0805 | 1 | C15 | None polar capacitor
100 | SMD_0805 | 4 | R35, R36, R51, R52 | Resistor
100n | SMD_0805 | 2 | C21, C24 | None polar capacitor
100nF | SMD_0805 | 6 | C1, C3, C4, C5, C8, C13 | None polar capacitor
10k | SMD_0805 | 5 | R2, R8, R9, R16, R17 | Resistor
10x10V | SMD_0805 | 1 | C14 | None polar capacitor
120 | SMD_0805 | 1 | R4 | Resistor
1uF | SMD_0805 | 1 | C12 | None polar capacitor
20k | RES-ADJ-SMD-Panasonic | 2 | R28, R44 | Agjustable resistor
22 | SMD_0805 | 2 | R58, R59 | Resistor
22uH | IND-1812 | 1 | L1
2k4 | SMD_0805 | 2 | R30, R47 | Resistor
330 | SMD_0805 | 2 | R37, R53 | Resistor
3k | SMD_0805 | 1 | R5 | Resistor
470uFx35V | CAPR-10/5 | 1 | C10 | Polar capacitor
4k7 | SMD_0805 | 6 | R32, R38, R39, R48, R54, R55 | Resistor
51k | SMD_0805 | 1 | R15 | Resistor
6.1V | DO214-AC | 1 | VD7 | TVS Diode
620 | SMD_0805 | 2 | R6, R7 | Resistor
680 | SMD_0805 | 4 | R26, R31, R42, R46 | Resistor
82k | SMD_0805 | 2 | R29, R45 | Resistor
8MHz | CSTCC-CRYSTAL | 1 | Q1 | Crystal oscillator
AOZ1282CI | SOT-23-6 | 1 | U5 | Buck regulator
BAV99 | SOT23-3 | 2 | U8, U9 | TVS diodes
BSS138 | SOT23-3PIN | 2 | Q3, Q4 | IG-FET N-Channel
CON_2 | DG142V-5.08-2 | 1 | XP3
CON_3 | MW-3M-2.0 | 3 | XP1, XP8, XP10
CON_4 | HEAD-1/4/2.54 | 2 | XP2, XP11
CON_8 | HEAD-1/8/2.54 | 2 | XP9, XP12
CON2_0 | MW-2M-2.0 | 1 | XP4
GREEN | SMD_0805 | 2 | VD2, VD3
IRLML6401TRPBF | SOT23-3PIN | 2 | Q2, Q5 | P-Channel
LM324 | SOIC-14 | 1 | U7 | OpAmp
LTC4054-4.2 | SOT753 | 1 | U6 | Buck regulator
MAX232 | SOIC-16 | 1 | U12 | RS232 transceiver
MC78LC33NTRG | SOT753 | 1 | U4 | Low dropout Linear Voltage Regulator
RED | SMD_0805 | 1 | VD1
SM712 | SOT23-3 | 2 | U2, U11 | TVS diodes
SS14 | DO214-AC | 1 | VD5 | Diode
ST485 | SO8-150mil | 1 | U10 | RS485 interface
STM32F072C8T6 | STM-LQFP48_L | 1 | U3 | ARM Cortex-M0 32-bit MCU, 64 KB Flash, 8 KB Internal RAM, 39 I/Os, 48-pin LQFP, -40 to 85 degC, Tray
SW_DIP/2.54 | DIP-SW/2.54/1 | 2 | SW1, SW3 | Switch
SW | SW_6/3.7 | 2 | SW2, SW4 | Switch
TJA1051 | SO8-150mil | 1 | U1
TL431 | SOT23-3 | 1 | VS1
USB | USB/SM0.8-6H5 | 1 | XP7

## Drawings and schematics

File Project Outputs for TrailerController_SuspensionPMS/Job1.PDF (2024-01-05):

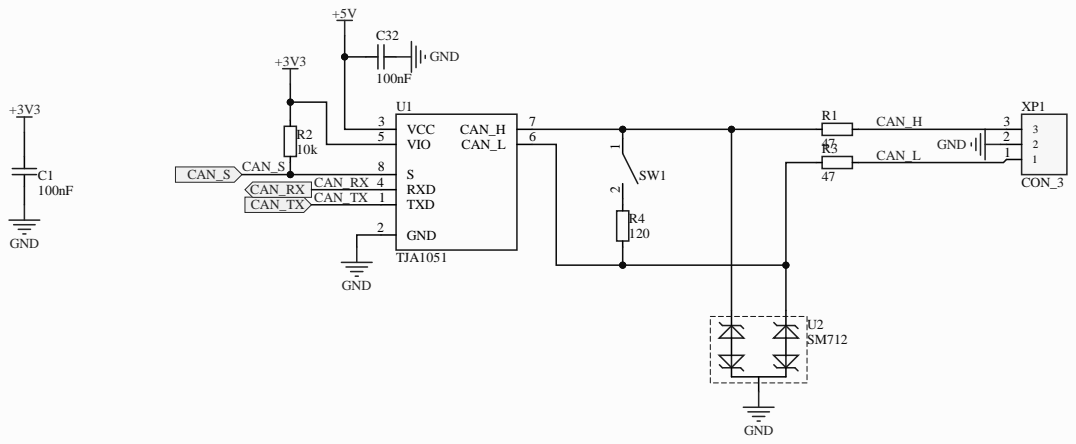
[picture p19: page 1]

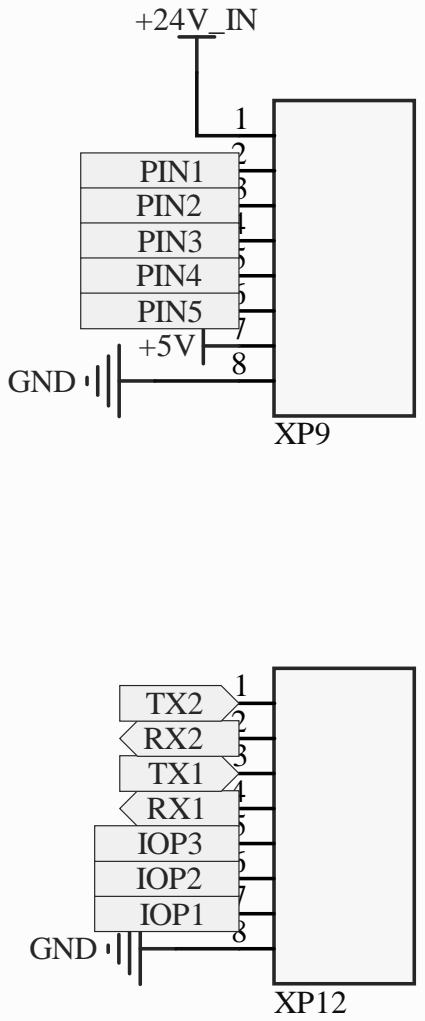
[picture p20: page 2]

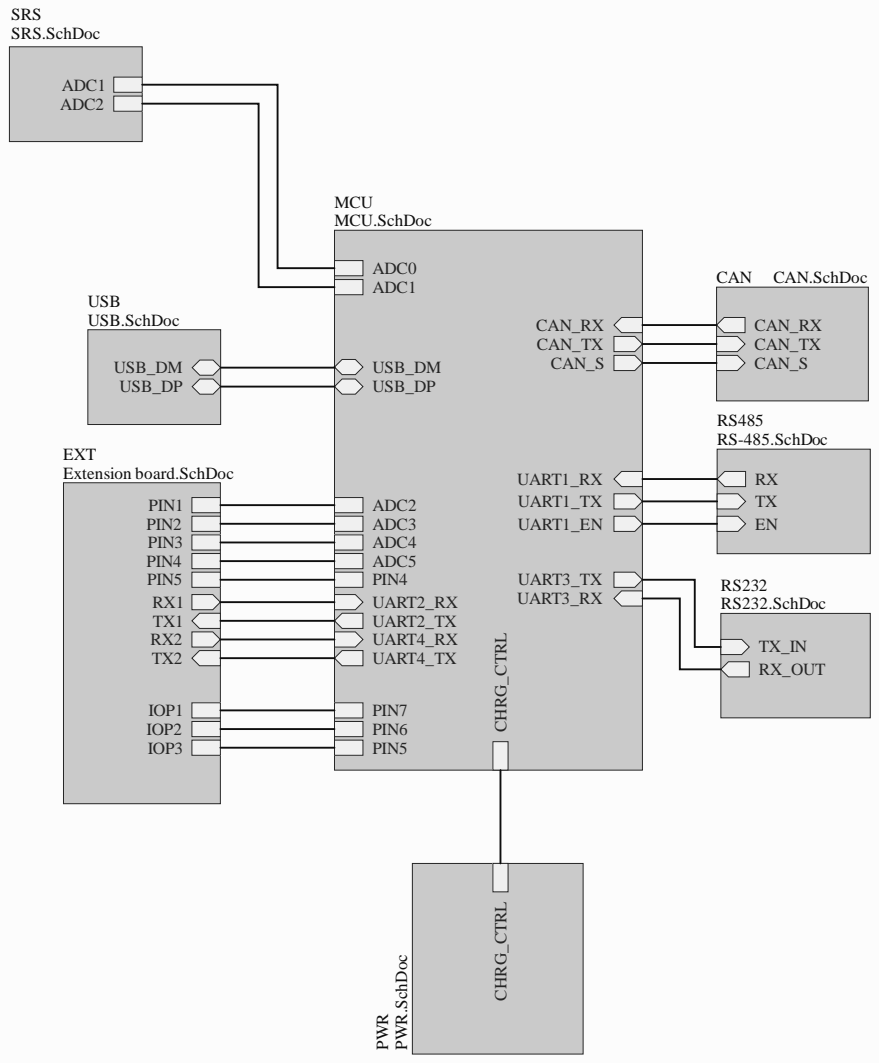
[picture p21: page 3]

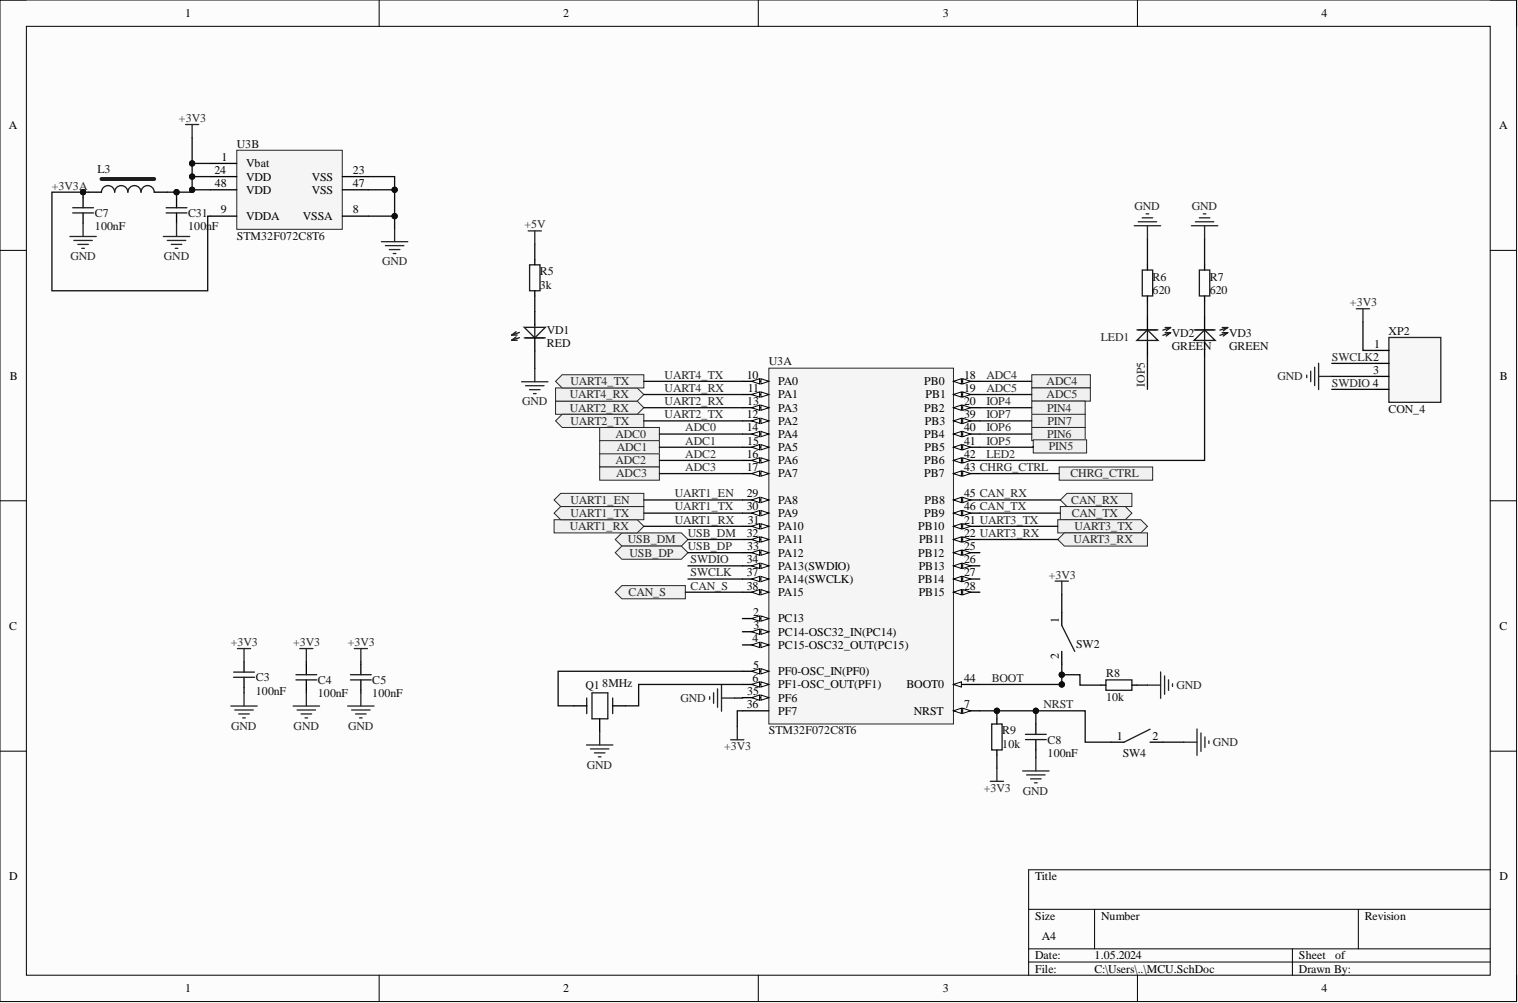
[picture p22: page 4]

2 4
4 8 | | 4 7

1 9 | A DC5
2 0 | I OP4
3 9 | I OP7
4 0 | I OP6

A DC1 1 5 | | 4 1 | I OP5
A DC2 1 6 | | 4 2 | L E D

3 5

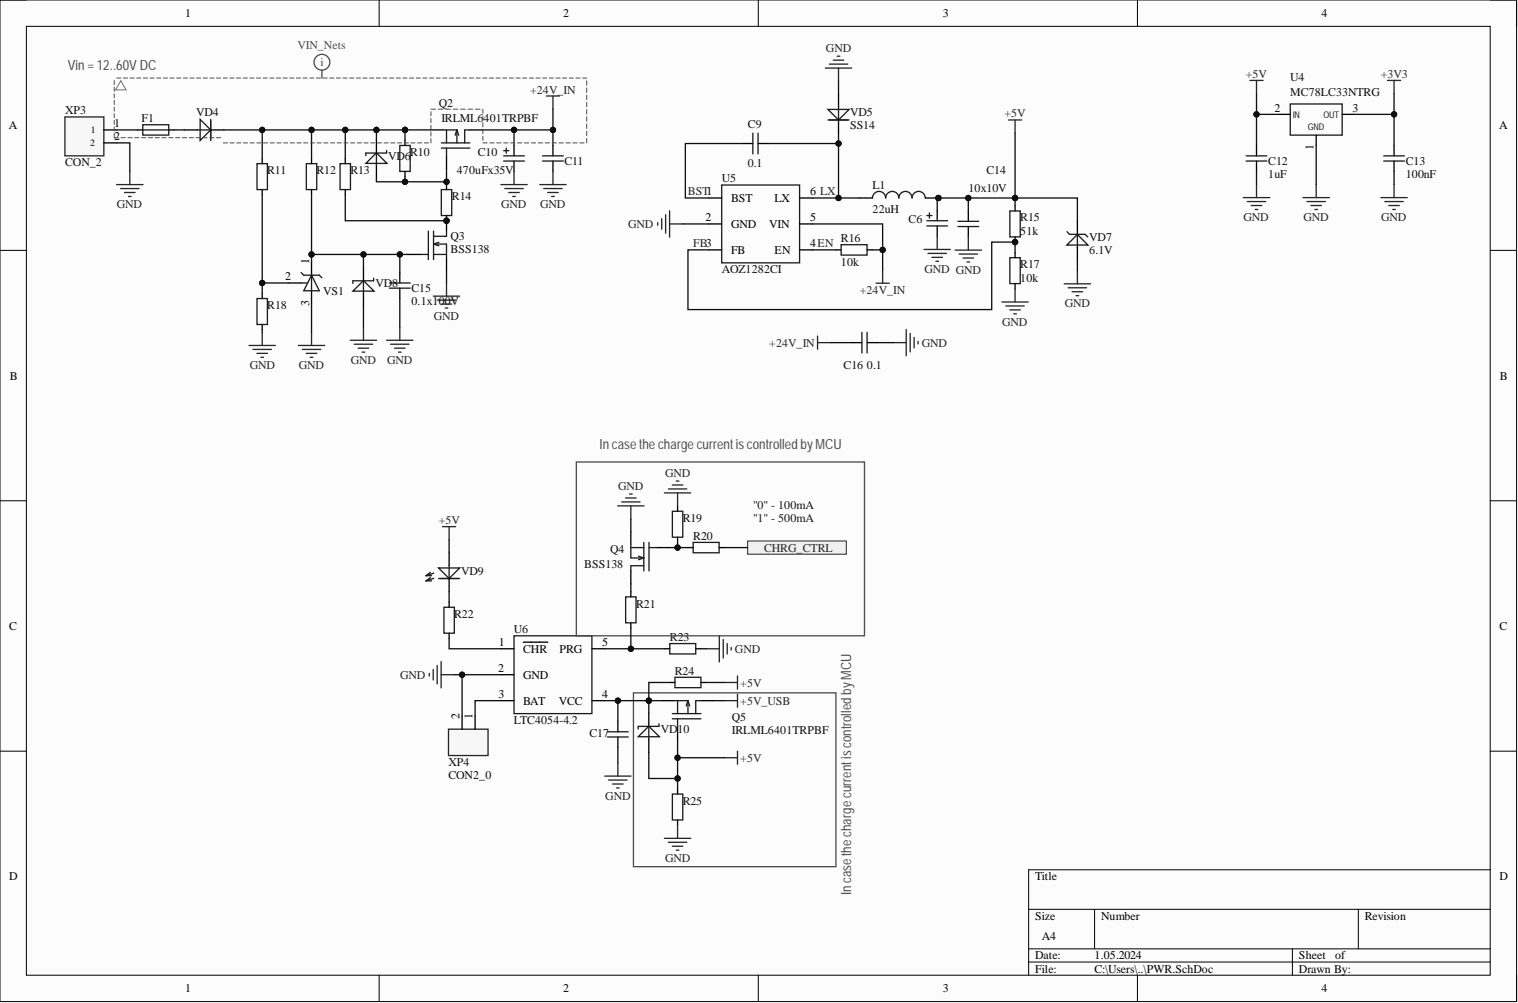
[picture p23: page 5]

In case the charge current is controlled by MCU

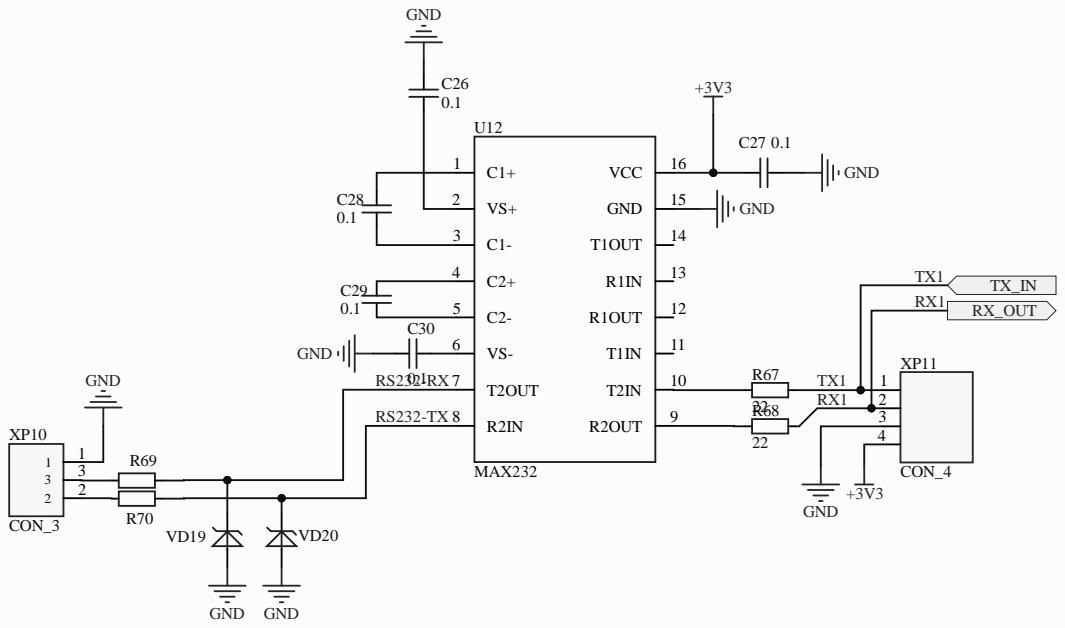
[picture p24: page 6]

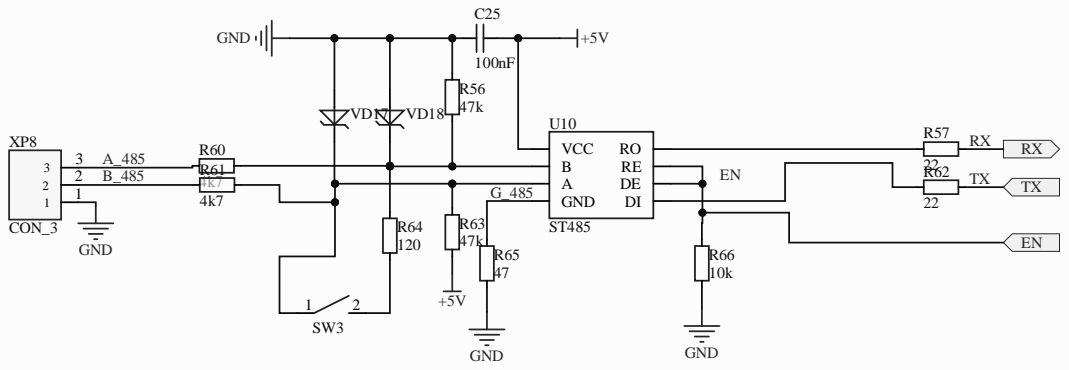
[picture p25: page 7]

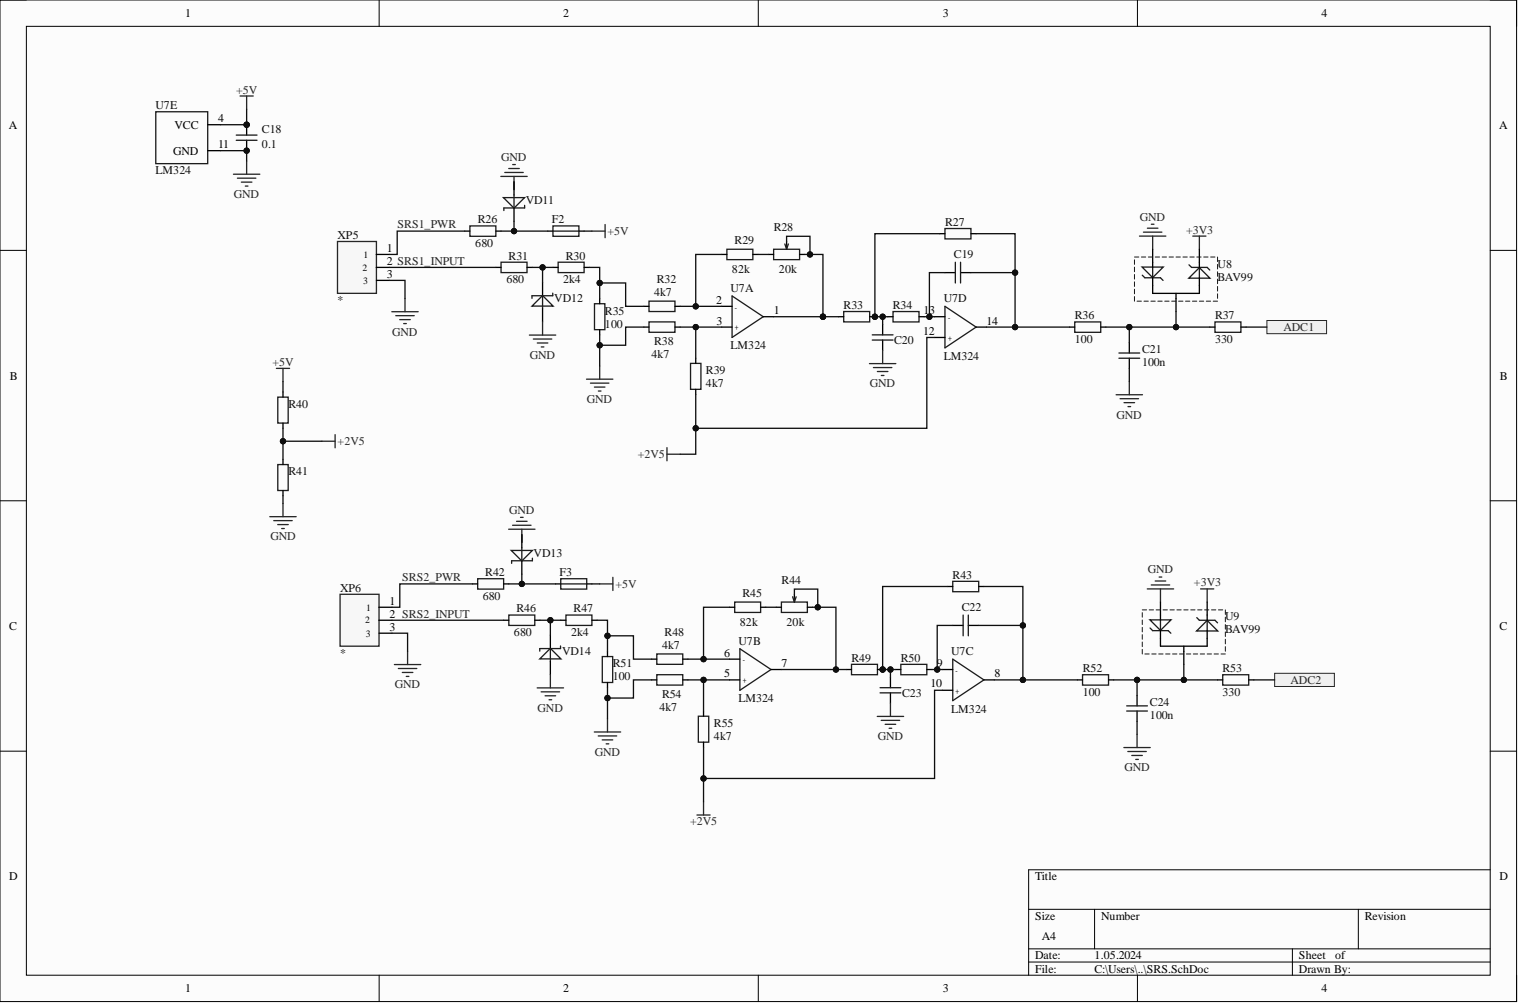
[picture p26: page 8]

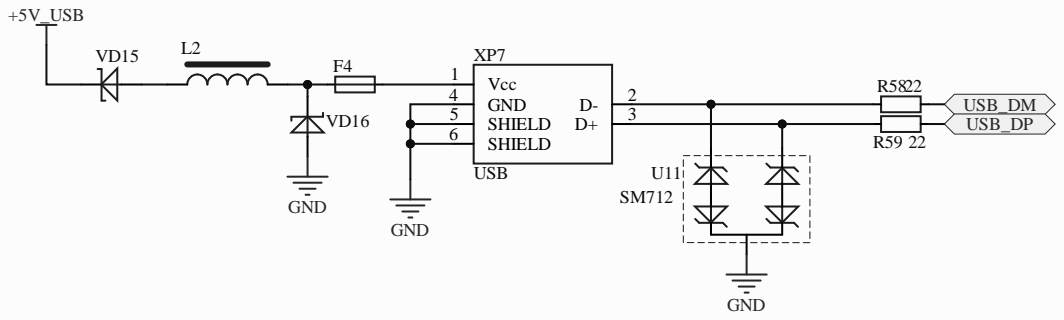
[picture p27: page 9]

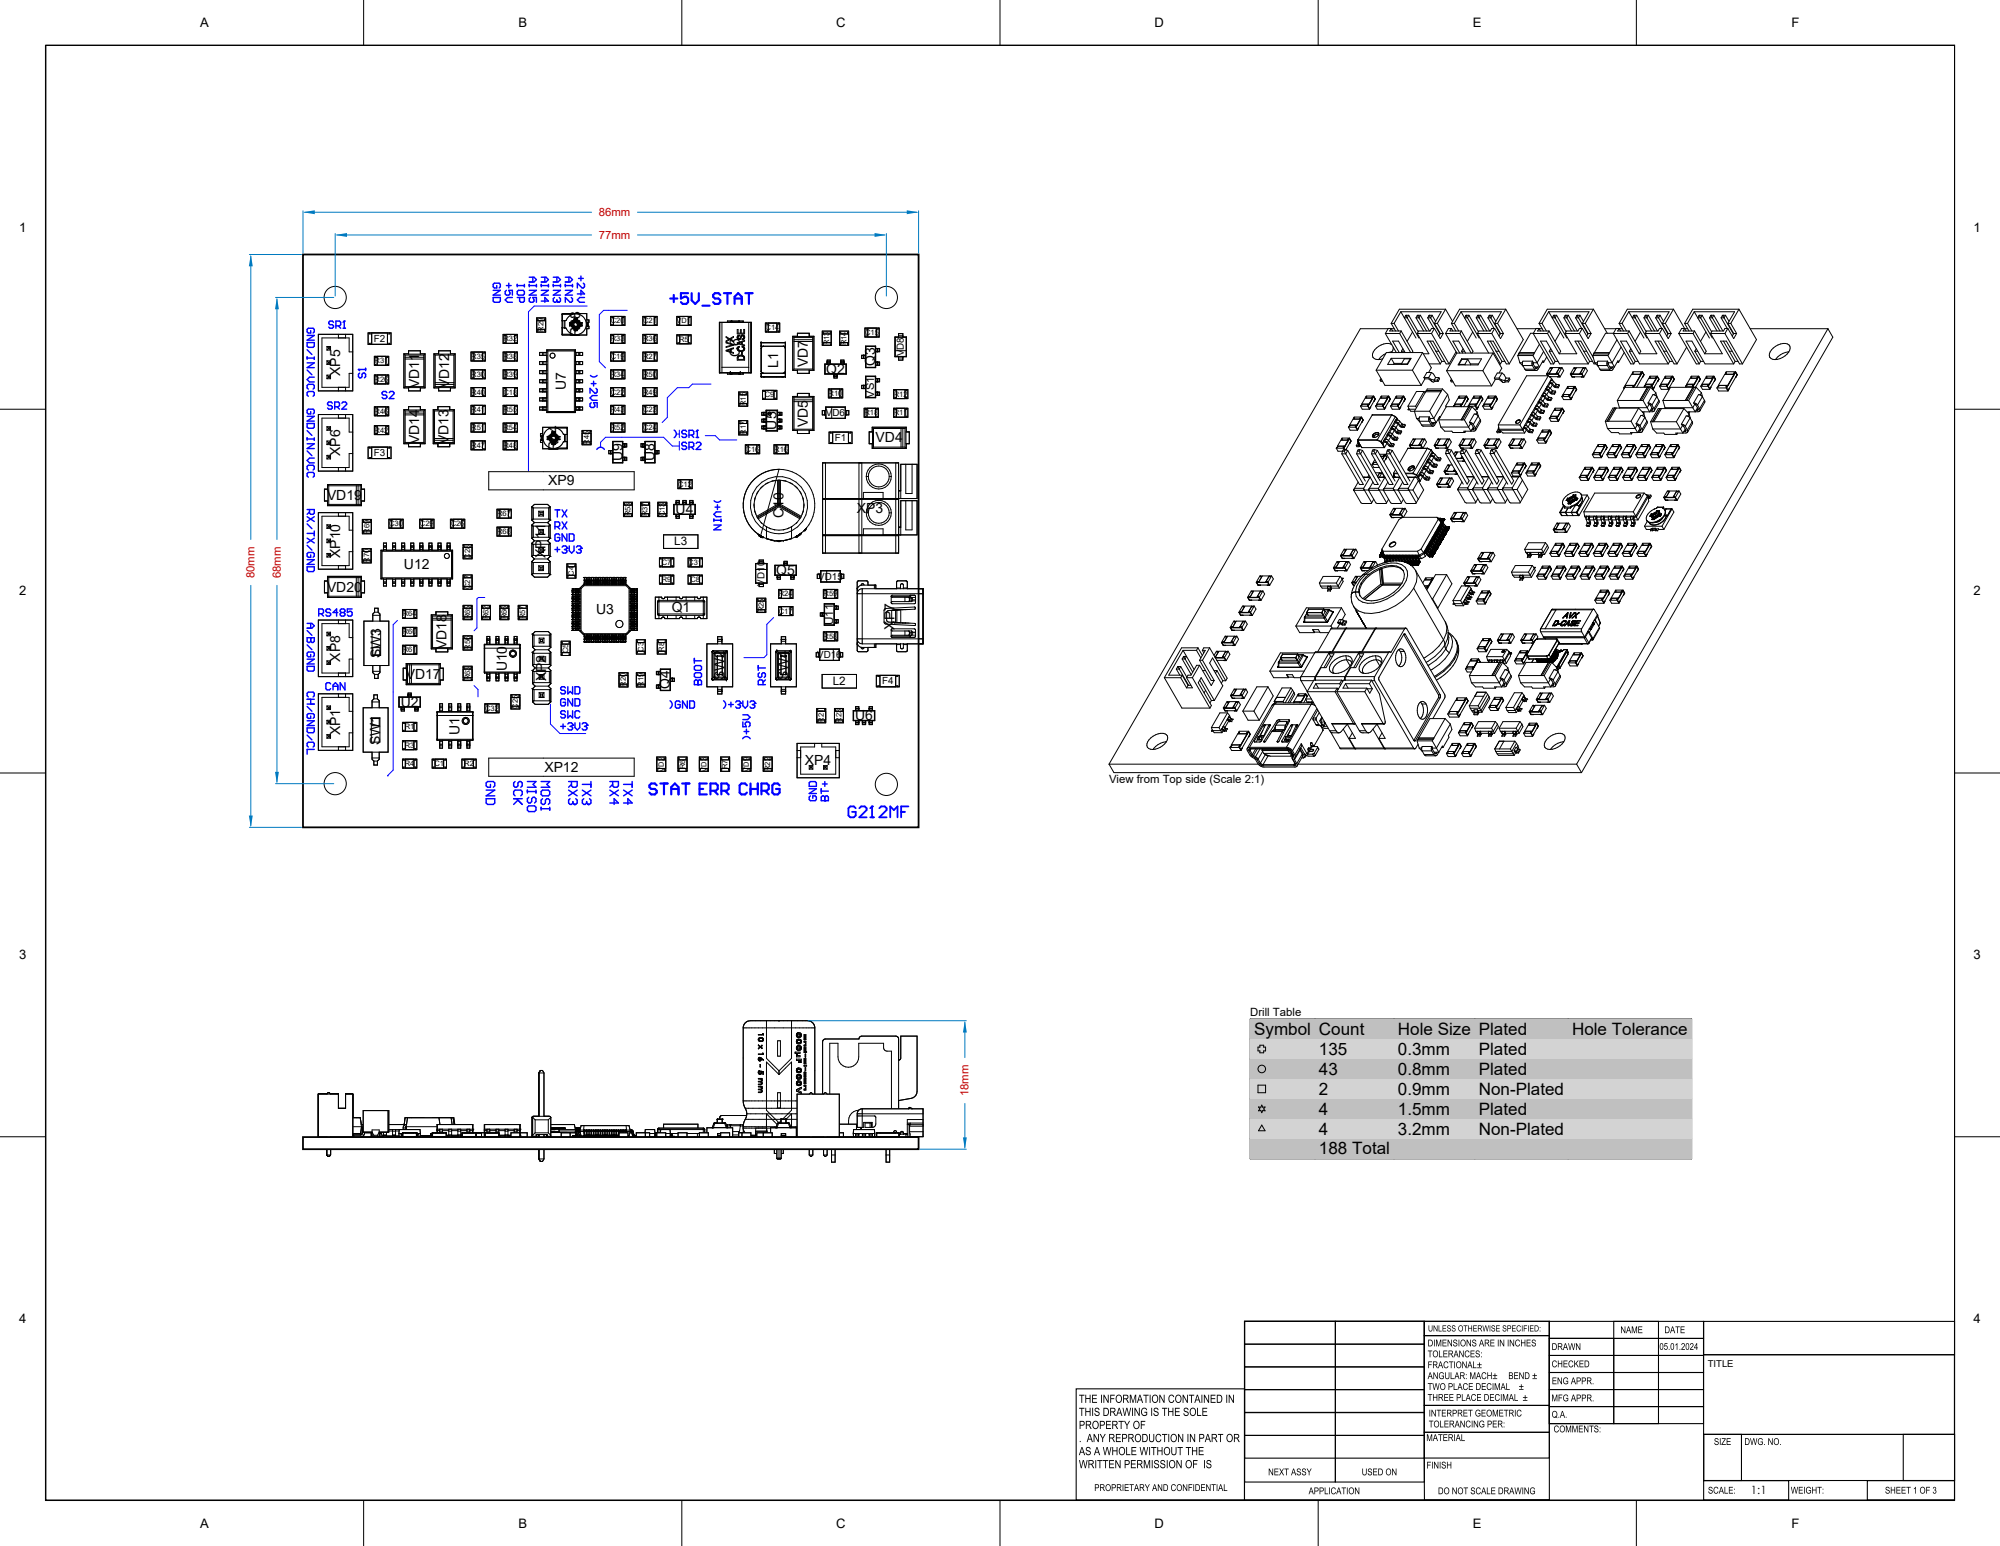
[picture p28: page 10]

View from Top side (Scale 2:1)

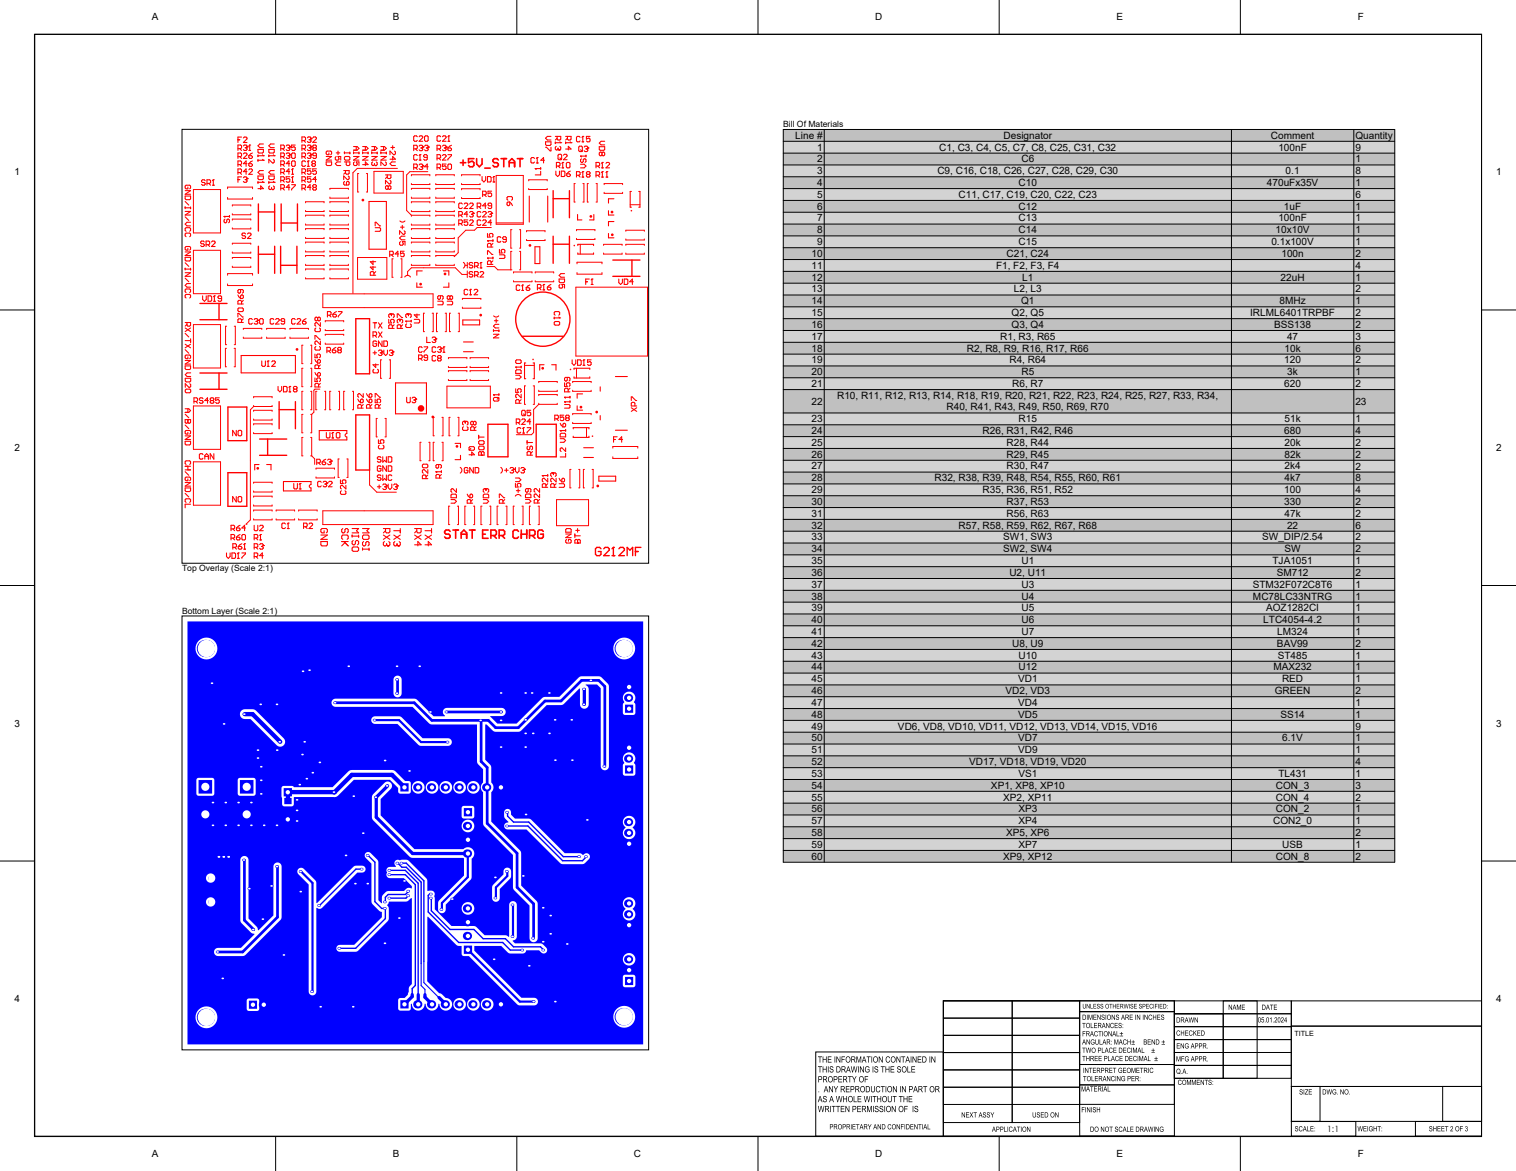
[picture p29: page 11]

Line #123456789 | C9, C16, C18, C26, C27, C28, C29, C30 | 0.1

Designator | Comment
C13 | 100nF | Quantity 918161111241212236212

C10 | 470uFx35V

C14 | 10x10V
C15 | 0.1x100V

10 | C21, C24 | 100n
11 | F1, F2, F3, F4
12 | L1 | 22uH
13 | L2, L3
14 | Q1 | 8MHz
15 | Q2, Q5 | IRLML6401TRPBF
16 | Q3, Q4 | BSS138
17 | R1, R3, R65 | 47
18 | R2, R8, R9, R16, R17, R66 | 10k
19 | R4, R64 | 120
20 | R5 | 3k
21 | R6, R7 | 620
22 | R10, R11, R12, R13, R14, R18, R19, R20, R21, R22, R23, R24, R25, R27, R33, R34, R40, R41, R43, R49, R50, R69, R70
34 | SW2, SW4 | SW | 2314222842262212111112111211911413211212
23 | R15 | 51k
24 | R26, R31, R42, R46 | 680
25 | R28, R44 | 20k
26 | R29, R45 | 82k
27 | R30, R47 | 2k4
28 | R32, R38, R39, R48, R54, R55, R60, R61 | 4k7
29 | R35, R36, R51, R52 | 100
30 | R37, R53 | 330
31 | R56, R63 | 47k
32 | R57, R58, R59, R62, R67, R68 | 22
33 | SW1, SW3 | SW_DIP/2.54

35 | U1 | TJA1051
36 | U2, U11 | SM712
37 | U3 | STM32F072C8T6
38 | U4 | MC78LC33NTRG
39 | U5 | AOZ1282CI
40 | U6 | LTC4054-4.2
41 | U7 | LM324
42 | U8, U9 | BAV99
43 | U10 | ST485
44 | U12 | MAX232
45 | VD1 | RED
46 | VD2, VD3 | GREEN
47 | VD4
48 | VD5 | SS14
49 | VD6, VD8, VD10, VD11, VD12, VD13, VD14, VD15, VD16
50 | VD7 | 6.1V
51 | VD9
52 | VD17, VD18, VD19, VD20
53 | VS1 | TL431
54 | XP1, XP8, XP10 | CON_3
55 | XP2, XP11 | CON_4
56 | XP3 | CON_2
57 | XP4 | CON2_0
58 | XP5, XP6
59 | XP7 | USB
60 | XP9, XP12 | CON_8

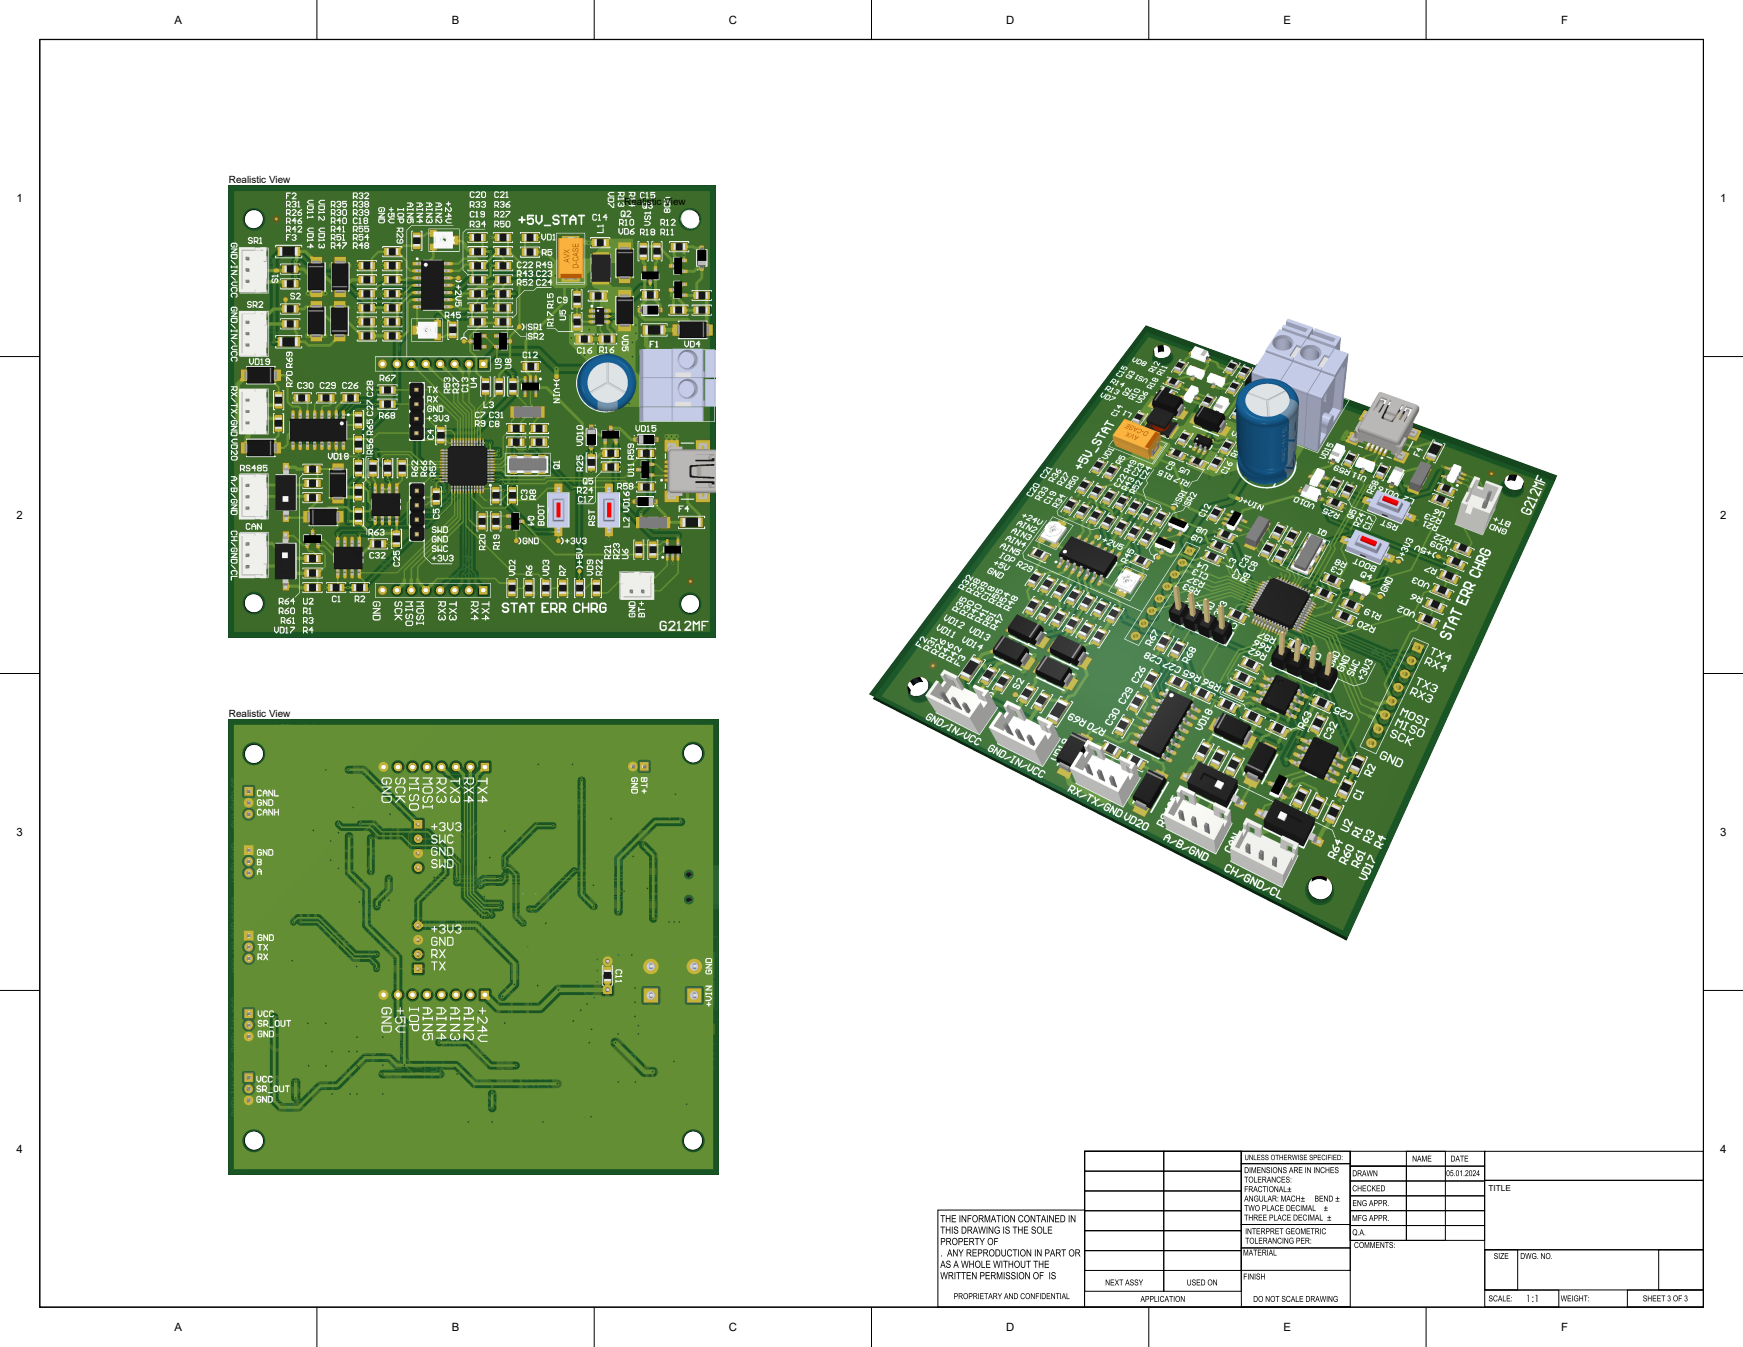
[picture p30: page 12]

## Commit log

2020-03-16 Added PCB
    [CAN.SchDoc, MCU.SchDoc, Main.SchDoc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]
2020-03-18 PCB shape changed
    [MCU.SchDoc, PWR.SchDoc, RS-485.SchDoc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]
2020-03-19 Fixed board outline
    [PWR.SchDoc, SRS.SchDoc]
2020-03-29 Added cubemx project
    [CAN.SchDoc, Extension board.SchDoc, MCU.SchDoc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]
2020-05-26 Rev1a was sent into production on PCBWay
    [CAN.SchDoc, Extension board.SchDoc, MCU.SchDoc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]
2020-07-25 Rev1A sent to production
    [Bill of Materials-TrailerController_SuspensionPMS.xls, CAN.SchDoc, MCU.SchDoc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]
2024-01-05 Added Draftsman document and README
    [TrailerController_SuspensionPMS.PrjPcb]
